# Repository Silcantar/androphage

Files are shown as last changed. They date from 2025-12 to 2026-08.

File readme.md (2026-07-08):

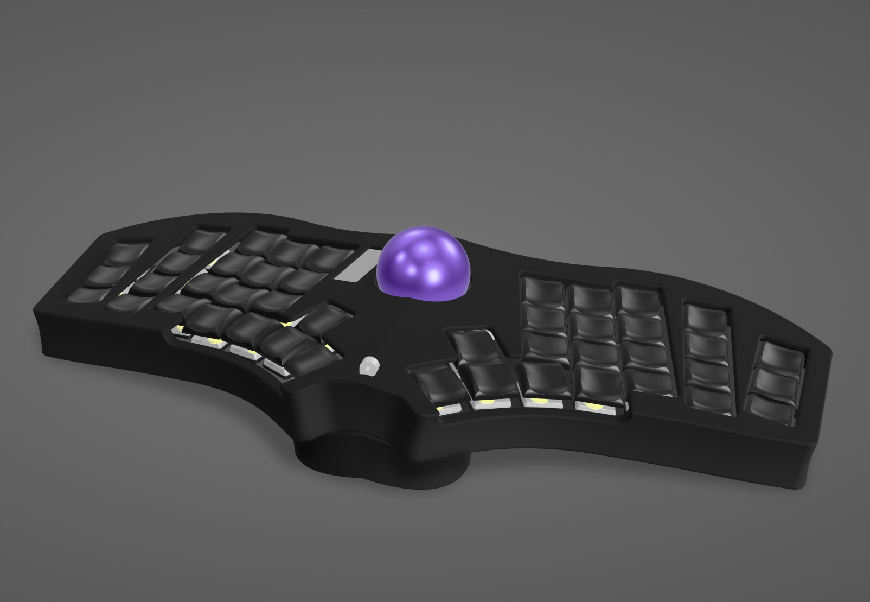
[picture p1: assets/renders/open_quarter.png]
androphage banner


# Androphage

There have been keyboards that are portable and there have been keyboards that
have integrated pointing devices, but to date there haven't been any keyboards
that combine both features. With this new design I intend to change that.

I'm reaching the end of the design phase on my new keyboard, Androphage. It's a
folding unibody split keyboard with 44 keys and a finger trackball in the
center. When the keyboard is closed, all the more delicate components ---
switches, keycaps, screen --- are protected inside the rugged SLS nylon case.
Additionally the trackball is secured in-place by the folding base of the
keyboard.

## Highlights:

- Unibody with fixed 15° split angle\* and 10° tent angle.

- 44 keys: 3x5, plus 4 thumb keys, row 5\*\* middle and ring finger keys, and
  key that can either be a very tucked thumb key or a row 5 index finger key.

- Rugged SLS nylon case.

- NRF52850 microcontroller and ZMK firmware for Bluetooth, dongle, or wired
  connectivity.

- Dual-sensor 34mm trackball is capable of 3-axis control, i.e. twist-to-scroll
  à la Kensington SlimBlade.

- Nice!View or similar screen for layer, pairing, and charging status.

- Low power consumption microcontroller and trackball sensors (PMW3610) paired
  with a 300 mAh LiPo battery for days or weeks of battery life.

- USB-C charging and connectivity.

- Designed for Chicago Steno or KLP Lamé keycaps but can potentially be adapted
  for other low-to-mid-profile keycaps.

- The custom hinges are SLM stainless steel for maximum durability.

- There is space inside the base for storing the charging cable.

- Unfolded dimensions: 290 x 135 x 62 mm

- Folded dimensions: 148 x 135 x 45 mm

\* Measured between the centerline of the keyboard and the axis of the index
finger key column.

\*\* That is, two rows below the home row, equivalent to the modifier row on an
ANSI/ISO keyboard.

## Additional Renders

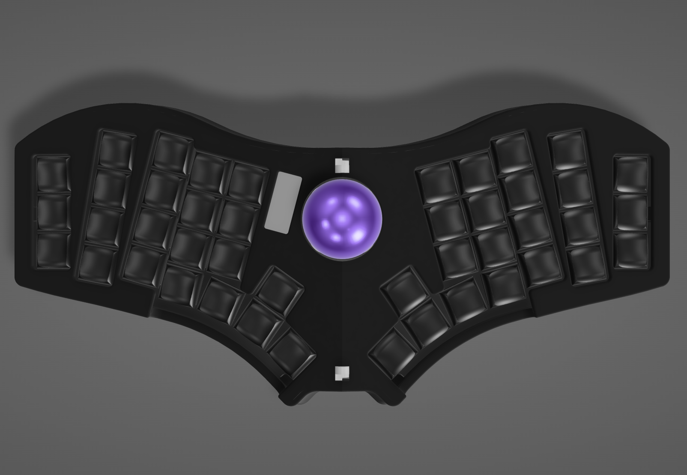
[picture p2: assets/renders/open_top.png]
Opened Top View


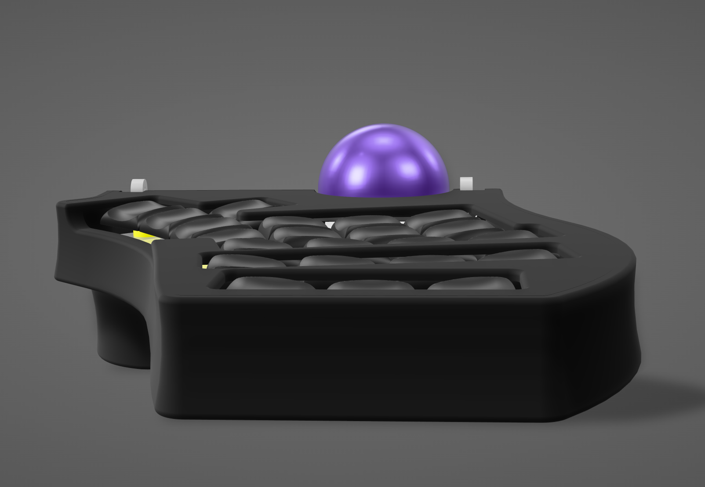
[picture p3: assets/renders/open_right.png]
Opened Right Profile


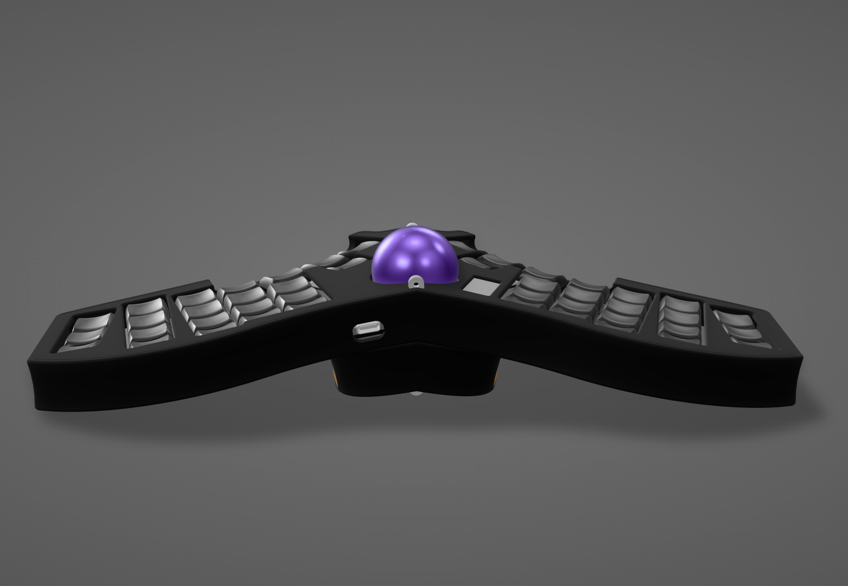
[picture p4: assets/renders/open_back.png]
Opened Back View


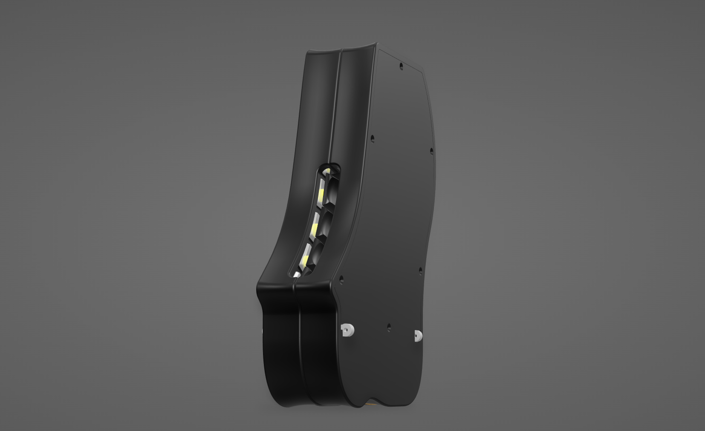
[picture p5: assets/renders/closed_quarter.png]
Closed Quarter View


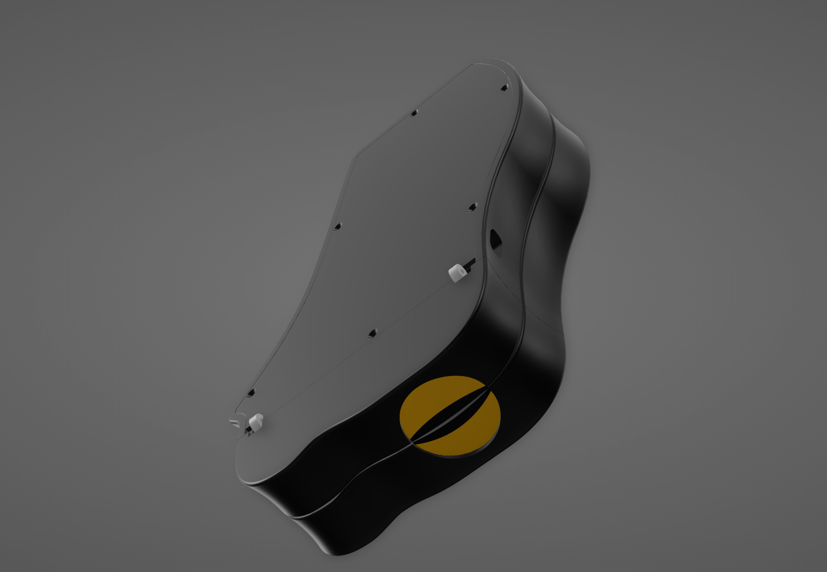
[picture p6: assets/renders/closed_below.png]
Closed Below View


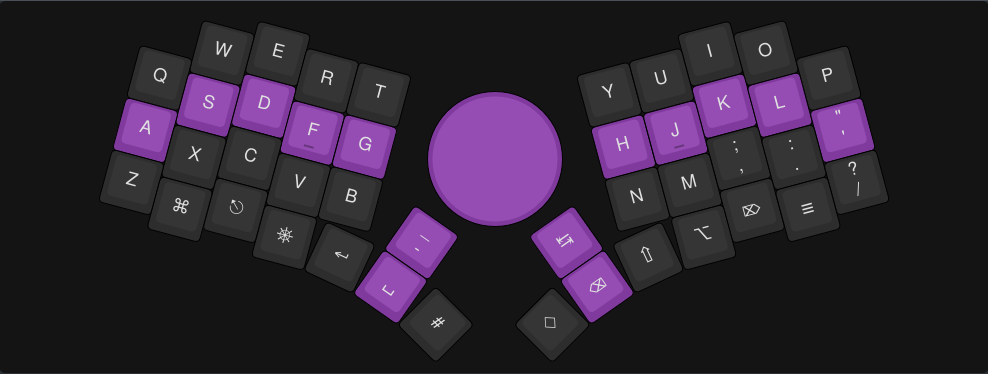
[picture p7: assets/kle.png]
Suggested Key Layout


## Open Source

This project is licensed under the CERN Open Hardware License, Strongly
Reciprocal 2.0.

---

> *Well, I saw the thing comin' out of the sky*
>
> *It had a-one long horn and one big eye*
>
> *I commenced to shakin' and I said, "Ooh-eee!*
>
> *It looks like a purple people eater to me!"*
>
> &mdash;Sheb Wooley

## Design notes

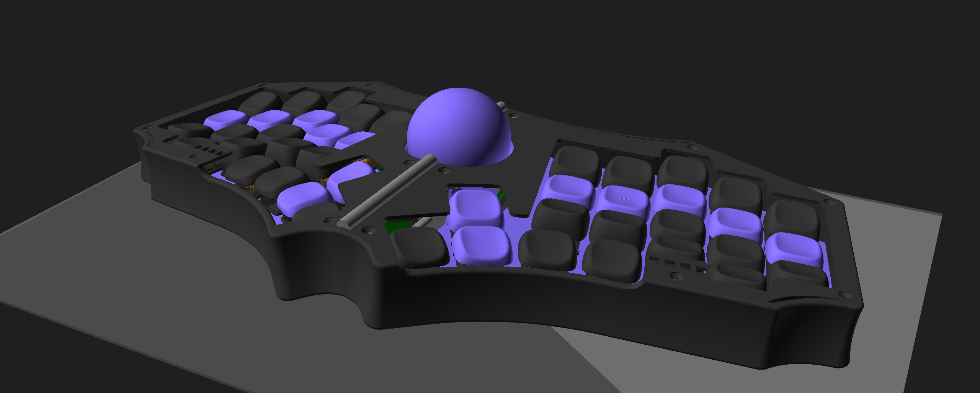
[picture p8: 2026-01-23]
assets/androphage_render.png

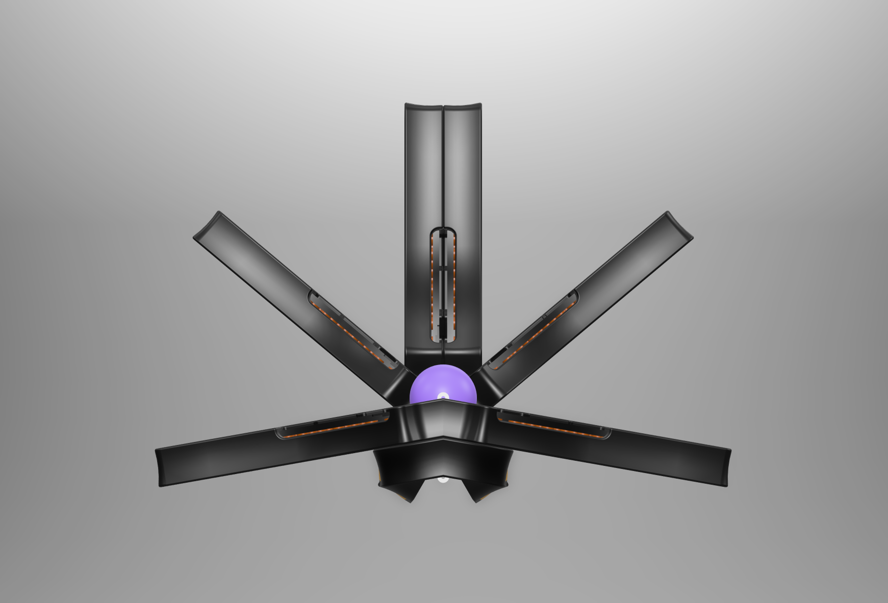
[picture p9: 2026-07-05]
assets/renders/front.png

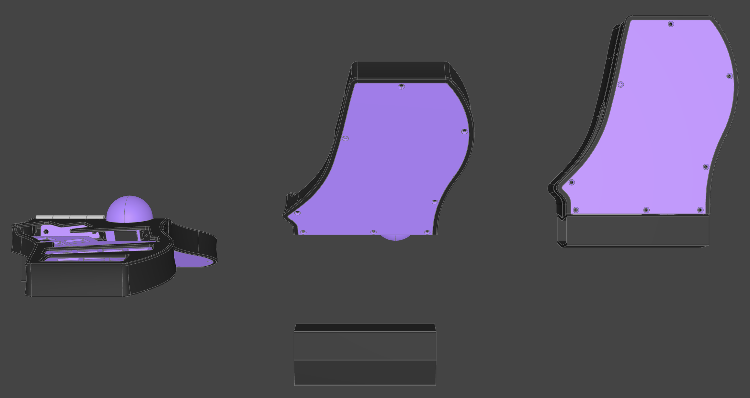
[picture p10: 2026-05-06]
assets/taking_flight.png

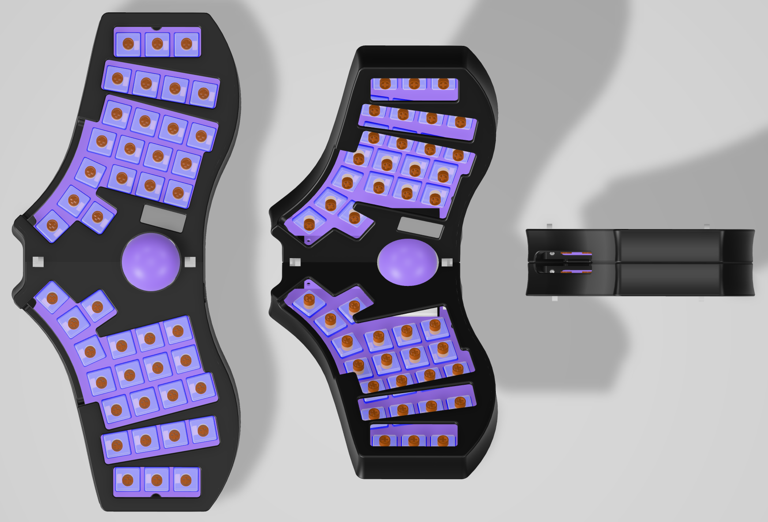
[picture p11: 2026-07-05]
assets/renders/top.png

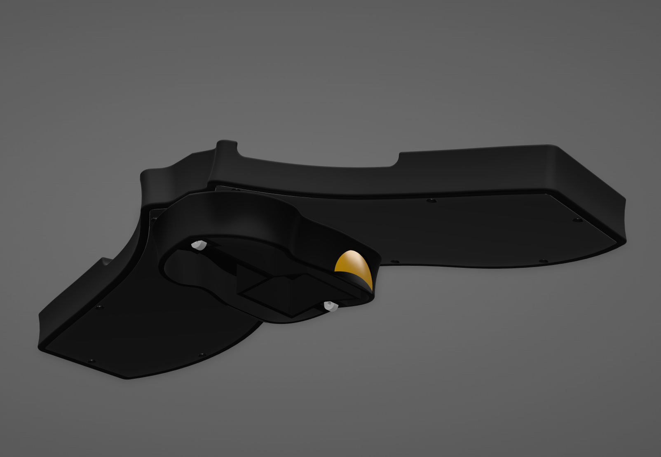
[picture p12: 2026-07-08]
assets/renders/open_below.png

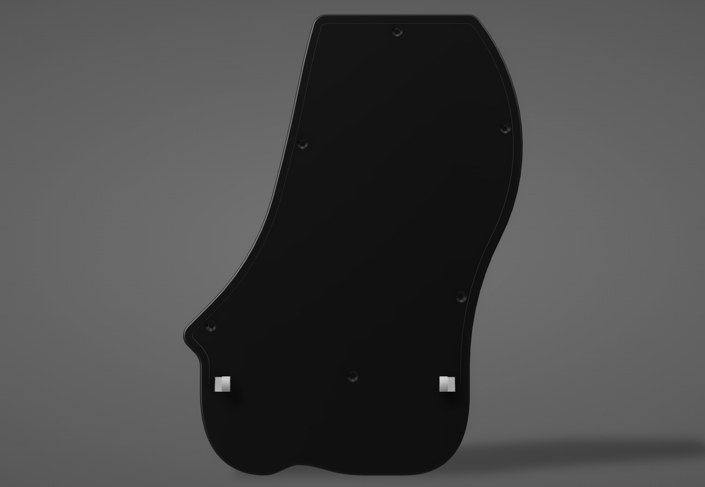
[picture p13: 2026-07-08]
assets/renders/closed_right.png

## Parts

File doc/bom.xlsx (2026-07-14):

Part | Specifications | Mouser Part # | LCSC Part # | Connector PCB | Control PCB | Matrix PCB | Sensor PCB | Other | Quantity | Unit Cost | Total Cost | Source | Link | Notes
Keycap set |  |  |  |  |  |  |  | 0 | 0 | $2.64 | $0.00 | 3dKeycap | https://3dkeycap.com/products/mx-chicago-steno-keycap-set?variant=46916802117890 | Minimum 2 R1, 10 R2, 10 R3, 10 R4, 6/4 R5, 6/8 thumb
BTU | Veichu VCN310 |  |  |  |  |  |  | 4 | 4 | $1.21 | $4.84 | AliBaba | https://www.alibaba.com/product-detail/VEICHU-VCN310-311-New-Stainless-Steel_1601020185379.html
Magnetic pogo pin connector | pair, 12-pin |  |  | 1 |  |  |  |  | 1 | $3.52 | $3.52 | AliBaba | https://www.alibaba.com/product-detail/Fool-proof-Customizable-2-12-Pin_1601813292668.html
Trackball Sensor | PMW-3610DM-SUDU |  |  |  |  |  | 2 |  | 2 | $5.90 | $11.80 | AliExpress | https://www.aliexpress.us/item/3256806932453023.html
Battery | 401230 |  |  |  |  |  |  | 1 | 1 | $7.99 | $7.99 | Amazon | https://a.co/d/0cnfUvY7
Heat-set insert | M2, brass |  |  |  |  |  |  | 32 | 32 | $0.04 | $1.28 | Amazon | https://a.co/d/0f5MURbA
Hot-swap socket |  |  |  |  |  | 44 |  |  | 44 | $0.14 | $6.16 | Amazon | https://a.co/d/0cJAZBIr
Key switch |  |  |  |  |  |  |  | 0 | 0 | $0.39 | $0.00 | Amazon | https://a.co/d/02MneUm9 | Kailh Choc V1/V2, Gateron KS-33
Magnet | 4x2 round |  |  |  |  |  |  | 4 | 4 | $0.03 | $0.12 | Amazon | https://a.co/d/02Mu1WZn
Screw | M2, round, 4mm |  |  |  |  |  |  | 6 | 6 | $0.06 | $0.36 | Amazon | https://a.co/d/04It1t0C
Screw | M2, countersink, 7mm |  |  |  |  |  |  | 26 | 26 | $0.08 | $2.08 | Amazon | https://a.co/d/0gQpGyUt
Trackball | 34-35 mm |  |  |  |  |  |  | 0 | 0 | $11.99 | $0.00 | Amazon | https://a.co/d/06izoJGP
O-Ring | 150 mm x 3.5 mm |  |  |  |  |  |  | 2 | 2 | $1.00 | $2.00 | Amazon | https://a.co/d/0eipM3TN
Bottom Plate | SLS Nylon |  |  |  |  |  |  | 2 | 2 | $7.42 | $14.84 | CraftCloud
Case, Left | SLS Nylon |  |  |  |  |  |  | 1 | 1 | $21.24 | $21.24 | CraftCloud
Case, Right | SLS Nylon |  |  |  |  |  |  | 1 | 1 | $21.24 | $21.24 | CraftCloud
Hinge | SLM 316 stainless steel |  |  |  |  |  |  | 2 | 2 | $4.56 | $9.12 | CraftCloud |  | Set of 4 leaves, unit cost for 20
PCB | VIK PMW3610-narrow |  |  |  |  |  | 2 |  | 2 | $0.63 | $1.26 | JLCPCB
PCB | VIK Magnetic Connector, pair |  |  | 2 |  |  |  |  | 2 | $1.97 | $3.94 | JLCPCB
PCB | Matrix, pair |  |  |  |  | 1 |  |  | 1 | $5.13 | $5.13 | JLCPCB
PCB | Control, pair |  |  |  | 1 |  |  |  | 1 | $5.45 | $5.45 | JLCPCB
VIK nice!nano adapter PCB |  |  |  |  |  |  |  | 1 | 1 | $0.66 | $0.66 | JLCPCB
Taper Pin | 5/0 |  |  |  |  |  |  | 8 | 8 | $0.45 | $3.60 | McMaster | https://www.mcmaster.com/98390A040/
Battery charger |  | 579-MCP73832T-2ACIOT | C38066 |  | 1 |  |  |  | 1 | $0.76 | $0.76 | Mouser | https://mou.sr/3QXacgq
Button Switch |  | 179-TS046643BK160SMT | C2845297 |  |  | 1 |  |  | 1 | $0.18 | $0.18 | Mouser | https://mou.sr/454Uz9S
Capacitor, 100nF |  | 187-CL21B104KBFNNNG | C14663 |  |  |  | 8 |  | 8 | $0.10 | $0.80 | Mouser | https://mou.sr/4pr6I2A
Capacitor, 10nF |  | 187-CL21B103KBANNNC | C57112 |  | 2 |  | 4 |  | 6 | $0.10 | $0.60 | Mouser | https://mou.sr/4fzanb4
Capacitor, 10uF |  | 187-CL21B106KQQNNNF |  |  |  |  | 2 |  | 2 | $0.12 | $0.24 | Mouser | https://mou.sr/44q3UJg
Capacitor, 1uF |  | 187-CL21B105KBFNFNE | C15849 |  |  |  | 2 |  | 2 | $0.12 | $0.24 | Mouser | https://mou.sr/4yljd3D
Capacitor, 3.3uF |  | 187-CL21B335KOQVPNE | C51412 |  |  |  | 2 |  | 2 | $0.38 | $0.76 | Mouser | https://mou.sr/4wMxyEM
Diode |  | 241-1N4148W_R1_00001 | C917030 |  |  | 44 |  |  | 44 | $0.11 | $4.84 | Mouser | https://mou.sr/3RBnNdt | Switch matrix diode
ESD Protection Diode Array |  | 947-RCLAMP0504FBTCT | C2688137 | 6 |  |  |  |  | 6 | $0.89 | $5.34 | Mouser | https://mou.sr/4vZcLxN
Ferrite Bead |  | 875-MI0805K601R-10 | C46550600 | 2 |  | 1 |  |  | 3 | $0.11 | $0.33 | Mouser | https://mou.sr/4pp1IeD
FPC cable |  | 640-512A0101A4064T | C5151956 |  |  |  |  | 7 | 7 | $1.13 | $7.91 | Mouser | https://mou.sr/4hdeuuC | Type A, 0.5mm pitch, 12-pin, [Length]
FPC Connector |  | 640-FFC2B35-12-G | C2906115 | 2 | 8 |  |  | 1 | 11 | $0.43 | $4.73 | Mouser | https://mou.sr/4wNFIwF
FPC connector, mini |  | 640-FFC2B28-12-G | C5213732 |  |  |  | 2 |  | 2 | $0.40 | $0.80 | Mouser | https://mou.sr/3RcmbXu
Fuse |  | 652-MF-PSMF050X-2 | C2833485 | 2 |  | 1 |  |  | 3 | $0.32 | $0.96 | Mouser | https://mou.sr/4ylZUXY
Holyiot 18010 MCU module |  | 713-113990556 |  |  | 1 |  |  |  | 1 | $9.11 | $9.11 | Mouser | https://mou.sr/4pa7teo
I/O Expander |  | 579-MCP23017-E/SS | C506653 |  |  | 2 |  |  | 2 | $1.69 | $3.38 | Mouser | https://mou.sr/4piFMBM
LED ARGB |  | 604-APFA3010SEKJ3ZGK | C2992675 |  |  | 1 |  |  | 1 | $0.76 | $0.76 | Mouser | https://mou.sr/4h7FKe0
Molex Picoblade Connector, 2 pin |  | 538-53398-0271 | C122410 |  | 1 |  |  |  | 1 | $0.54 | $0.54 | Mouser | https://mou.sr/4yl9kTn | Battery connector
Molex Picoblade Connector, 4 pin |  | 538-53398-0471 | C17617036 |  | 1 |  |  |  | 1 | $0.74 | $0.74 | Mouser | https://mou.sr/4feluoj | SWD connector
MOSFET |  | 241-PJA3401AR100001 | C82360 |  | 1 |  |  |  | 1 | $0.33 | $0.33 | Mouser | https://mou.sr/4flJENZ
Resistor, 10 kOhm |  | 603-RC0805FR-0710KL |  |  |  | 12 |  |  | 12 | $0.10 | $1.20 | Mouser | https://mou.sr/4f3aewt
Resistor, 100 kOhm |  | 603-RC0805FR-07100KL |  |  | 1 |  |  |  | 1 | $0.10 | $0.10 | Mouser | https://mou.sr/4vWF2F0
Resistor, 2 kOhm |  | 603-RC0805FR-072KL |  |  | 1 |  |  |  | 1 | $0.10 | $0.10 | Mouser | https://mou.sr/4wdXjxJ
Resistor, 2 MOhm |  | 603-RC0805FR-072ML |  |  | 1 |  | 2 |  | 3 | $0.10 | $0.30 | Mouser | https://mou.sr/4fAjXuf
Resistor, 270 Ohm |  | 603-RC0805FR-07270RL |  |  |  | 1 |  |  | 1 | $0.10 | $0.10 | Mouser | https://mou.sr/4wIlUdJ
Resistor, 330 Ohm |  | 603-RC0805FR-07330RL |  |  |  | 1 |  |  | 1 | $0.10 | $0.10 | Mouser | https://mou.sr/4hdepqP
Resistor, 470 Ohm |  | 603-RC0805FR-07470RL |  |  |  | 1 |  |  | 1 | $0.10 | $0.10 | Mouser | https://mou.sr/4ydr1UW
Resistor, 5.1 kOhm |  | 603-RC0805FR-075K1L |  |  |  | 2 |  |  | 2 | $0.10 | $0.20 | Mouser | https://mou.sr/4wGJ2JJ
Resistor, 8.2 kOhm |  | 603-RC0805FR-078K2L |  |  | 1 |  |  |  | 1 | $0.10 | $0.10 | Mouser | https://mou.sr/3T05u20
Resistor, 820 kOhm |  | 603-RC0805FR-07820KL |  |  | 1 |  |  |  | 1 | $0.10 | $0.10 | Mouser | https://mou.sr/4f0LeWy
Schottky diode |  | 621-1N5819HW-F | C191023 |  | 1 |  |  |  | 1 | $0.29 | $0.29 | Mouser | https://mou.sr/452zhd3
USB-C receptacle |  | 640-USB4930-00-A |  |  |  | 1 |  |  | 1 | $0.52 | $0.52 | Mouser | https://mou.sr/4pkxr0t
Voltage Regulator |  | 757-TCR2EF19LMCT | C146366 |  |  |  | 2 |  | 2 | $0.14 | $0.28 | Mouser | https://mou.sr/4hevIrr | 1.8V 200mA output
Voltage Regulator |  | 595-TLV75733PDYDR | C17703066 |  | 1 |  |  |  | 1 | $0.37 | $0.37 | Mouser | https://mou.sr/4wFoi4W
Switch Plate | Acrylic |  |  |  |  |  |  | 2 | 2 | $3.45 | $6.90 | SendCutSend
Screen | nice!view |  |  |  |  |  |  | 1 | 1 | $20.00 | $20.00 | Typeractive | https://typeractive.xyz/products/nice-view
59 |  | 34 | 21 | 15 | 23 | 113 | 28 | 101 | 280 |  | $200.74

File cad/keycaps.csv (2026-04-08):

Profile | Color | Count 1 | Count 2
R1 | Black | 4 | 0
R1 | Purple | 2 | 6
R2 | Black | 26 | 28
R2 | Purple | 2 | 0
R3 | Purple | 8 | 8
R3 Homing | Purple | 2 | 2

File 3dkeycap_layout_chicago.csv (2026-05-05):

x | y | z | x_rotation | y_rotation | z_rotation | row | size | material | color | legend1_text | legend1_font_family | legend1_font_size | legend1_font_bold | legend1_font_italic | legend1_font_color | legend1_offset_x | legend1_offset_y | legend1_align | legend1_rotation | legend2_text | legend2_font_family | legend2_font_size | legend2_font_bold | legend2_font_italic | legend2_font_color | legend2_offset_x | legend2_offset_y | legend2_align | legend2_rotation | legend3_text | legend3_font_family | legend3_font_size | legend3_font_bold | legend3_font_italic | legend3_font_color | legend3_offset_x | legend3_offset_y | legend3_align | legend3_rotation | legend4_text | legend4_font_family | legend4_font_size | legend4_font_bold | legend4_font_italic | legend4_font_color | legend4_offset_x | legend4_offset_y | legend4_align | legend4_rotation
-90 | 0 | -55.25 | 0 | 0 | 0 | R2 | 1u | resin | black | E | Trebuchet MS | 5 | FALSE | FALSE | white | 0 | 0 | Center | 0 |  |  | null | FALSE | FALSE |  | 0 | 0 | Center | 0 |  |  | null | FALSE | FALSE |  | 0 | 0 | Center | 0 |  |  | null | FALSE | FALSE |  | 0 | 0 | Center | 0
90 | 0 | -55.25 | 0 | 0 | 0 | R2 | 1u | resin | black | I | Trebuchet MS | 5 | FALSE | FALSE | white | 0 | 0 | Center | 0 |  |  | null | FALSE | FALSE |  | 0 | 0 | Center | 0 |  |  | null | FALSE | FALSE |  | 0 | 0 | Center | 0 |  |  | null | FALSE | FALSE |  | 0 | 0 | Center | 0
-108 | 0 | -51 | 0 | 0 | 0 | R2 | 1u | resin | black | W | Trebuchet MS | 5 | FALSE | FALSE | white | 0 | 0 | Center | 0 |  |  | null | FALSE | FALSE |  | 0 | 0 | Center | 0 |  |  | null | FALSE | FALSE |  | 0 | 0 | Center | 0 |  |  | null | FALSE | FALSE |  | 0 | 0 | Center | 0
-72 | 0 | -51 | 0 | 0 | 0 | R2 | 1u | resin | black | R | Trebuchet MS | 5 | FALSE | FALSE | white | 0 | 0 | Center | 0 |  |  | null | FALSE | FALSE |  | 0 | 0 | Center | 0 |  |  | null | FALSE | FALSE |  | 0 | 0 | Center | 0 |  |  | null | FALSE | FALSE |  | 0 | 0 | Center | 0
-54 | 0 | -51 | 0 | 0 | 0 | R2 | 1u | resin | black | T | Trebuchet MS | 5 | FALSE | FALSE | white | 0 | 0 | Center | 0 |  |  | null | FALSE | FALSE |  | 0 | 0 | Center | 0 |  |  | null | FALSE | FALSE |  | 0 | 0 | Center | 0 |  |  | null | FALSE | FALSE |  | 0 | 0 | Center | 0
54 | 0 | -51 | 0 | 0 | 0 | R2 | 1u | resin | black | Y | Trebuchet MS | 5 | FALSE | FALSE | white | 0 | 0 | Center | 0 |  |  | null | FALSE | FALSE |  | 0 | 0 | Center | 0 |  |  | null | FALSE | FALSE |  | 0 | 0 | Center | 0 |  |  | null | FALSE | FALSE |  | 0 | 0 | Center | 0
72 | 0 | -51 | 0 | 0 | 0 | R2 | 1u | resin | black | U | Trebuchet MS | 5 | FALSE | FALSE | white | 0 | 0 | Center | 0 |  |  | null | FALSE | FALSE |  | 0 | 0 | Center | 0 |  |  | null | FALSE | FALSE |  | 0 | 0 | Center | 0 |  |  | null | FALSE | FALSE |  | 0 | 0 | Center | 0
108 | 0 | -51 | 0 | 0 | 0 | R2 | 1u | resin | black | O | Trebuchet MS | 5 | FALSE | FALSE | white | 0 | 0 | Center | 0 |  |  | null | FALSE | FALSE |  | 0 | 0 | Center | 0 |  |  | null | FALSE | FALSE |  | 0 | 0 | Center | 0 |  |  | null | FALSE | FALSE |  | 0 | 0 | Center | 0
-126 | 0 | -38.25 | 0 | 0 | 0 | R2 | 1u | resin | black | Q | Trebuchet MS | 5 | FALSE | FALSE | white | 0 | 0 | Center | 0 |  |  | null | FALSE | FALSE |  | 0 | 0 | Center | 0 |  |  | null | FALSE | FALSE |  | 0 | 0 | Center | 0 |  |  | null | FALSE | FALSE |  | 0 | 0 | Center | 0
-90 | 0 | -38.25 | 0 | 0 | 0 | R3 | 1u | resin | purple | D | Trebuchet MS | 5 | FALSE | FALSE | white | 0 | 0 | Center | 0 |  |  | null | FALSE | FALSE |  | 0 | 0 | Center | 0 |  |  | null | FALSE | FALSE |  | 0 | 0 | Center | 0 |  |  | null | FALSE | FALSE |  | 0 | 0 | Center | 0
90 | 0 | -38.25 | 0 | 0 | 0 | R3 | 1u | resin | purple | K | Trebuchet MS | 5 | FALSE | FALSE | white | 0 | 0 | Center | 0 |  |  | null | FALSE | FALSE |  | 0 | 0 | Center | 0 |  |  | null | FALSE | FALSE |  | 0 | 0 | Center | 0 |  |  | null | FALSE | FALSE |  | 0 | 0 | Center | 0
126 | 0 | -38.25 | 0 | 0 | 0 | R2 | 1u | resin | black | P | Trebuchet MS | 5 | FALSE | FALSE | white | 0 | 0 | Center | 0 |  |  | null | FALSE | FALSE |  | 0 | 0 | Center | 0 |  |  | null | FALSE | FALSE |  | 0 | 0 | Center | 0 |  |  | null | FALSE | FALSE |  | 0 | 0 | Center | 0
-108 | 0 | -34 | 0 | 0 | 0 | R3 | 1u | resin | purple | S | Trebuchet MS | 5 | FALSE | FALSE | white | 0 | 0 | Center | 0 |  |  | null | FALSE | FALSE |  | 0 | 0 | Center | 0 |  |  | null | FALSE | FALSE |  | 0 | 0 | Center | 0 |  |  | null | FALSE | FALSE |  | 0 | 0 | Center | 0
-72 | 0 | -34 | 0 | 0 | 0 | R3 | 1u-homing | resin | purple | F | Trebuchet MS | 5 | FALSE | FALSE | white | 0 | 0 | Center | 0 |  |  | null | FALSE | FALSE |  | 0 | 0 | Center | 0 |  |  | null | FALSE | FALSE |  | 0 | 0 | Center | 0 |  |  | null | FALSE | FALSE |  | 0 | 0 | Center | 0
-54 | 0 | -34 | 0 | 0 | 0 | R3 | 1u | resin | purple | G | Trebuchet MS | 5 | FALSE | FALSE | white | 0 | 0 | Center | 0 |  |  | null | FALSE | FALSE |  | 0 | 0 | Center | 0 |  |  | null | FALSE | FALSE |  | 0 | 0 | Center | 0 |  |  | null | FALSE | FALSE |  | 0 | 0 | Center | 0
54 | 0 | -34 | 0 | 0 | 0 | R3 | 1u | resin | purple | H | Trebuchet MS | 5 | FALSE | FALSE | white | 0 | 0 | Center | 0 |  |  | null | FALSE | FALSE |  | 0 | 0 | Center | 0 |  |  | null | FALSE | FALSE |  | 0 | 0 | Center | 0 |  |  | null | FALSE | FALSE |  | 0 | 0 | Center | 0
72 | 0 | -34 | 0 | 0 | 0 | R3 | 1u-homing | resin | purple | J | Trebuchet MS | 5 | FALSE | FALSE | white | 0 | 0 | Center | 0 |  |  | null | FALSE | FALSE |  | 0 | 0 | Center | 0 |  |  | null | FALSE | FALSE |  | 0 | 0 | Center | 0 |  |  | null | FALSE | FALSE |  | 0 | 0 | Center | 0
108 | 0 | -34 | 0 | 0 | 0 | R3 | 1u | resin | purple | L | Trebuchet MS | 5 | FALSE | FALSE | white | 0 | 0 | Center | 0 |  |  | null | FALSE | FALSE |  | 0 | 0 | Center | 0 |  |  | null | FALSE | FALSE |  | 0 | 0 | Center | 0 |  |  | null | FALSE | FALSE |  | 0 | 0 | Center | 0
-126 | 0 | -21.25 | 0 | 0 | 0 | R3 | 1u | resin | purple | A | Trebuchet MS | 5 | FALSE | FALSE | white | 0 | 0 | Center | 0 |  |  | null | FALSE | FALSE |  | 0 | 0 | Center | 0 |  |  | null | FALSE | FALSE |  | 0 | 0 | Center | 0 |  |  | null | FALSE | FALSE |  | 0 | 0 | Center | 0
-90 | 0 | -21.25 | 0 | 0 | 0 | R4 | 1u | resin | black | C | Trebuchet MS | 5 | FALSE | FALSE | white | 0 | 0 | Center | 0 |  |  | null | FALSE | FALSE |  | 0 | 0 | Center | 0 |  |  | null | FALSE | FALSE |  | 0 | 0 | Center | 0 |  |  | null | FALSE | FALSE |  | 0 | 0 | Center | 0
90 | 0 | -21.25 | 0 | 0 | 0 | R4 | 1u | resin | black | , | Trebuchet MS | 5 | FALSE | FALSE | white | 0 | 0 | Center | 0 |  |  | null | FALSE | FALSE |  | 0 | 0 | Center | 0 |  |  | null | FALSE | FALSE |  | 0 | 0 | Center | 0 |  |  | null | FALSE | FALSE |  | 0 | 0 | Center | 0
126 | 0 | -21.25 | 0 | 0 | 0 | R3 | 1u | resin | purple | ; | Trebuchet MS | 5 | FALSE | FALSE | white | 0 | 0 | Center | 0 |  |  | null | FALSE | FALSE |  | 0 | 0 | Center | 0 |  |  | null | FALSE | FALSE |  | 0 | 0 | Center | 0 |  |  | null | FALSE | FALSE |  | 0 | 0 | Center | 0
-108 | 0 | -17 | 0 | 0 | 0 | R4 | 1u | resin | black | X | Trebuchet MS | 5 | FALSE | FALSE | white | 0 | 0 | Center | 0 |  |  | null | FALSE | FALSE |  | 0 | 0 | Center | 0 |  |  | null | FALSE | FALSE |  | 0 | 0 | Center | 0 |  |  | null | FALSE | FALSE |  | 0 | 0 | Center | 0
-72 | 0 | -17 | 0 | 0 | 0 | R4 | 1u | resin | black | V | Trebuchet MS | 5 | FALSE | FALSE | white | 0 | 0 | Center | 0 |  |  | null | FALSE | FALSE |  | 0 | 0 | Center | 0 |  |  | null | FALSE | FALSE |  | 0 | 0 | Center | 0 |  |  | null | FALSE | FALSE |  | 0 | 0 | Center | 0
-54 | 0 | -17 | 0 | 0 | 0 | R4 | 1u | resin | black | B | Trebuchet MS | 5 | FALSE | FALSE | white | 0 | 0 | Center | 0 |  |  | null | FALSE | FALSE |  | 0 | 0 | Center | 0 |  |  | null | FALSE | FALSE |  | 0 | 0 | Center | 0 |  |  | null | FALSE | FALSE |  | 0 | 0 | Center | 0
-36 | 0 | -17 | 0 | 0 | 0 | R1 | 1u | resin | purple | TabL | Trebuchet MS | 5 | FALSE | FALSE | white | 0 | 0 | Center | 0 |  |  | null | FALSE | FALSE |  | 0 | 0 | Center | 0 |  |  | null | FALSE | FALSE |  | 0 | 0 | Center | 0 |  |  | null | FALSE | FALSE |  | 0 | 0 | Center | 0
36 | 0 | -17 | 0 | 0 | 0 | R1 | 1u | resin | purple | TabR | Trebuchet MS | 5 | FALSE | FALSE | white | 0 | 0 | Center | 0 |  |  | null | FALSE | FALSE |  | 0 | 0 | Center | 0 |  |  | null | FALSE | FALSE |  | 0 | 0 | Center | 0 |  |  | null | FALSE | FALSE |  | 0 | 0 | Center | 0
54 | 0 | -17 | 0 | 0 | 0 | R4 | 1u | resin | black | N | Trebuchet MS | 5 | FALSE | FALSE | white | 0 | 0 | Center | 0 |  |  | null | FALSE | FALSE |  | 0 | 0 | Center | 0 |  |  | null | FALSE | FALSE |  | 0 | 0 | Center | 0 |  |  | null | FALSE | FALSE |  | 0 | 0 | Center | 0
72 | 0 | -17 | 0 | 0 | 0 | R4 | 1u | resin | black | M | Trebuchet MS | 5 | FALSE | FALSE | white | 0 | 0 | Center | 0 |  |  | null | FALSE | FALSE |  | 0 | 0 | Center | 0 |  |  | null | FALSE | FALSE |  | 0 | 0 | Center | 0 |  |  | null | FALSE | FALSE |  | 0 | 0 | Center | 0
108 | 0 | -17 | 0 | 0 | 0 | R4 | 1u | resin | black | . | Trebuchet MS | 5 | FALSE | FALSE | white | 0 | 0 | Center | 0 |  |  | null | FALSE | FALSE |  | 0 | 0 | Center | 0 |  |  | null | FALSE | FALSE |  | 0 | 0 | Center | 0 |  |  | null | FALSE | FALSE |  | 0 | 0 | Center | 0
-126 | 0 | -4.25 | 0 | 0 | 0 | R4 | 1u | resin | black | Z | Trebuchet MS | 5 | FALSE | FALSE | white | 0 | 0 | Center | 0 |  |  | null | FALSE | FALSE |  | 0 | 0 | Center | 0 |  |  | null | FALSE | FALSE |  | 0 | 0 | Center | 0 |  |  | null | FALSE | FALSE |  | 0 | 0 | Center | 0
-90 | 0 | -4.25 | 0 | 0 | 0 | R1 | 1u | resin | black | Esc | Trebuchet MS | 5 | FALSE | FALSE | white | 0 | 0 | Center | 0 |  |  | null | FALSE | FALSE |  | 0 | 0 | Center | 0 |  |  | null | FALSE | FALSE |  | 0 | 0 | Center | 0 |  |  | null | FALSE | FALSE |  | 0 | 0 | Center | 0
90 | 0 | -4.25 | 0 | 0 | 0 | R1 | 1u | resin | black | Del | Trebuchet MS | 5 | FALSE | FALSE | white | 0 | 0 | Center | 0 |  |  | null | FALSE | FALSE |  | 0 | 0 | Center | 0 |  |  | null | FALSE | FALSE |  | 0 | 0 | Center | 0 |  |  | null | FALSE | FALSE |  | 0 | 0 | Center | 0
126 | 0 | -4.25 | 0 | 0 | 0 | R4 | 1u | resin | black | / | Trebuchet MS | 5 | FALSE | FALSE | white | 0 | 0 | Center | 0 |  |  | null | FALSE | FALSE |  | 0 | 0 | Center | 0 |  |  | null | FALSE | FALSE |  | 0 | 0 | Center | 0 |  |  | null | FALSE | FALSE |  | 0 | 0 | Center | 0
-108 | 0 | 0 | 0 | 0 | 0 | R1 | 1u | resin | black | CW | Trebuchet MS | 5 | FALSE | FALSE | white | 0 | 0 | Center | 0 |  |  | null | FALSE | FALSE |  | 0 | 0 | Center | 0 |  |  | null | FALSE | FALSE |  | 0 | 0 | Center | 0 |  |  | null | FALSE | FALSE |  | 0 | 0 | Center | 0
-72 | 0 | 0 | 0 | 0 | 0 | R1 | 1u | resin | black | Ctrl | Trebuchet MS | 5 | FALSE | FALSE | white | 0 | 0 | Center | 0 |  |  | null | FALSE | FALSE |  | 0 | 0 | Center | 0 |  |  | null | FALSE | FALSE |  | 0 | 0 | Center | 0 |  |  | null | FALSE | FALSE |  | 0 | 0 | Center | 0
-54 | 0 | 0 | 0 | 0 | 0 | R2 | 1u | resin | black | Ret | Trebuchet MS | 5 | FALSE | FALSE | white | 0 | 0 | Center | 0 |  |  | null | FALSE | FALSE |  | 0 | 0 | Center | 0 |  |  | null | FALSE | FALSE |  | 0 | 0 | Center | 0 |  |  | null | FALSE | FALSE |  | 0 | 0 | Center | 0
-36 | 0 | 0 | 0 | 0 | 0 | R2 | 1u | resin | purple | Spc | Trebuchet MS | 5 | FALSE | FALSE | white | 0 | 0 | Center | 0 |  |  | null | FALSE | FALSE |  | 0 | 0 | Center | 0 |  |  | null | FALSE | FALSE |  | 0 | 0 | Center | 0 |  |  | null | FALSE | FALSE |  | 0 | 0 | Center | 0
-18 | 0 | 0 | 0 | 0 | 0 | R2 | 1u | resin | black | Num | Trebuchet MS | 5 | FALSE | FALSE | white | 0 | 0 | Center | 0 |  |  | null | FALSE | FALSE |  | 0 | 0 | Center | 0 |  |  | null | FALSE | FALSE |  | 0 | 0 | Center | 0 |  |  | null | FALSE | FALSE |  | 0 | 0 | Center | 0
18 | 0 | 0 | 0 | 0 | 0 | R2 | 1u | resin | black | Nav | Trebuchet MS | 5 | FALSE | FALSE | white | 0 | 0 | Center | 0 |  |  | null | FALSE | FALSE |  | 0 | 0 | Center | 0 |  |  | null | FALSE | FALSE |  | 0 | 0 | Center | 0 |  |  | null | FALSE | FALSE |  | 0 | 0 | Center | 0
36 | 0 | 0 | 0 | 0 | 0 | R2 | 1u | resin | purple | Bspc | Trebuchet MS | 5 | FALSE | FALSE | white | 0 | 0 | Center | 0 |  |  | null | FALSE | FALSE |  | 0 | 0 | Center | 0 |  |  | null | FALSE | FALSE |  | 0 | 0 | Center | 0 |  |  | null | FALSE | FALSE |  | 0 | 0 | Center | 0
54 | 0 | 0 | 0 | 0 | 0 | R2 | 1u | resin | black | Sft | Trebuchet MS | 5 | FALSE | FALSE | white | 0 | 0 | Center | 0 |  |  | null | FALSE | FALSE |  | 0 | 0 | Center | 0 |  |  | null | FALSE | FALSE |  | 0 | 0 | Center | 0 |  |  | null | FALSE | FALSE |  | 0 | 0 | Center | 0
72 | 0 | 0 | 0 | 0 | 0 | R1 | 1u | resin | black | Menu | Trebuchet MS | 5 | FALSE | FALSE | white | 0 | 0 | Center | 0 |  |  | null | FALSE | FALSE |  | 0 | 0 | Center | 0 |  |  | null | FALSE | FALSE |  | 0 | 0 | Center | 0 |  |  | null | FALSE | FALSE |  | 0 | 0 | Center | 0
108 | 0 | 0 | 0 | 0 | 0 | R1 | 1u | resin | black | Caps | Trebuchet MS | 5 | FALSE | FALSE | white | 0 | 0 | Center | 0 |  |  | null | FALSE | FALSE |  | 0 | 0 | Center | 0 |  |  | null | FALSE | FALSE |  | 0 | 0 | Center | 0 |  |  | null | FALSE | FALSE |  | 0 | 0 | Center | 0
-72 | 0 | 17 | 0 | 0 | 0 | R2 | 1u | resin | black | Ctrl | Trebuchet MS | 5 | FALSE | FALSE | white | 0 | 0 | Center | 0 |  |  | null | FALSE | FALSE |  | 0 | 0 | Center | 0 |  |  | null | FALSE | FALSE |  | 0 | 0 | Center | 0 |  |  | null | FALSE | FALSE |  | 0 | 0 | Center | 0
72 | 0 | 17 | 0 | 0 | 0 | R2 | 1u | resin | black | Menu | Trebuchet MS | 5 | FALSE | FALSE | white | 0 | 0 | Center | 0 |  |  | null | FALSE | FALSE |  | 0 | 0 | Center | 0 |  |  | null | FALSE | FALSE |  | 0 | 0 | Center | 0 |  |  | null | FALSE | FALSE |  | 0 | 0 | Center | 0

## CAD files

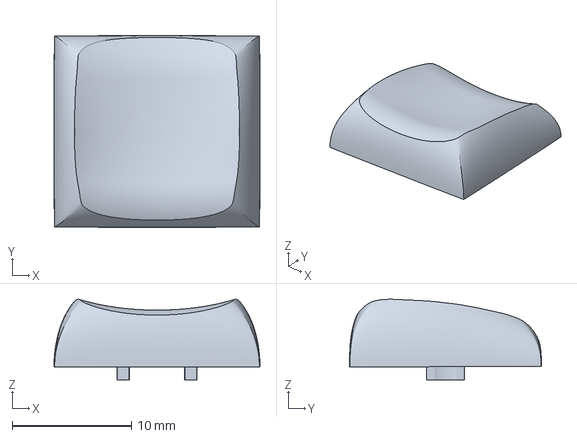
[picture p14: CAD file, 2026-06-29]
cad/components/keycaps/Choc_Chicago_Steno_R1.3mf
17.3 x 16.1 x 6.77 mm

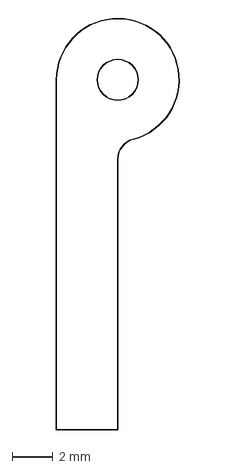
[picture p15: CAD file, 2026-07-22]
cad/production/hinge_knuckle_plate.dxf
6.22 x 20.2 mm

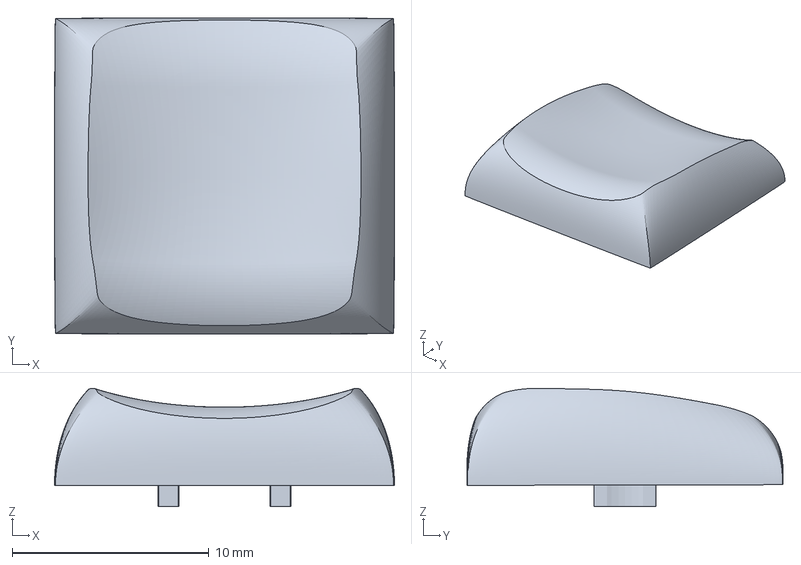
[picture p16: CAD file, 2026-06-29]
cad/components/keycaps/Choc_Chicago_Steno_R2.3mf
17.3 x 16.1 x 6.02 mm

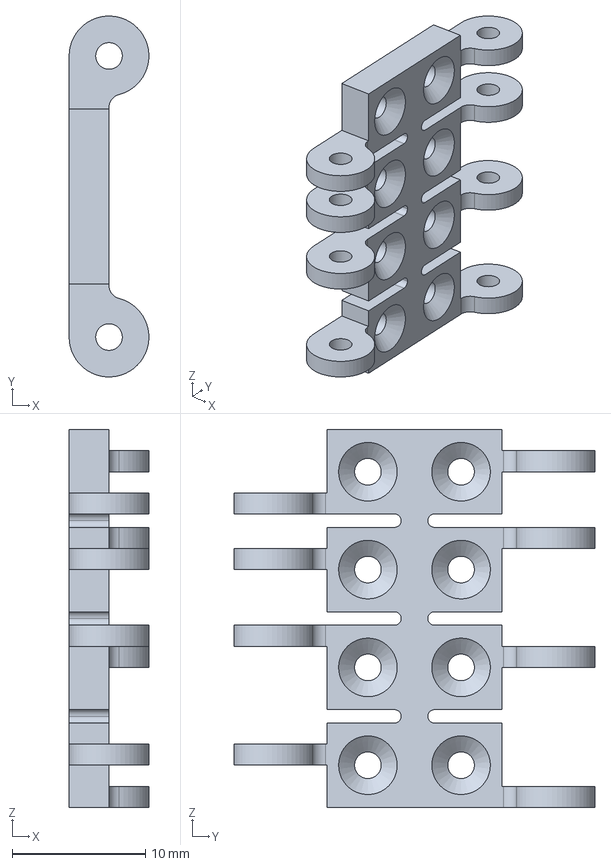
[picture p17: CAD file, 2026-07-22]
cad/production/knife_hinge_multi.step
6.00 x 27.1 x 28.4 mm

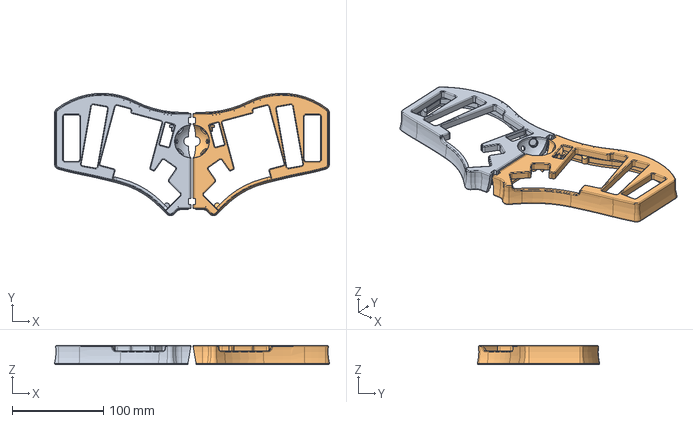
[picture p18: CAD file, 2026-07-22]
cad/production/case_combined.step
300.9 x 133.9 x 20.8 mm

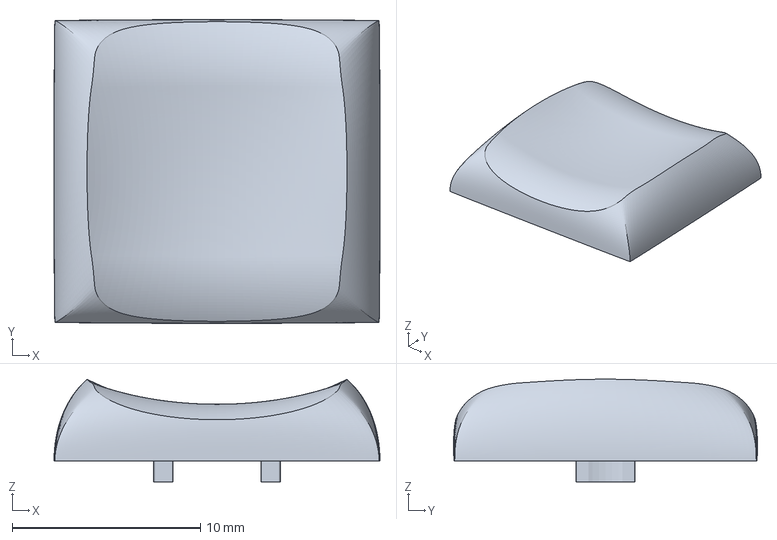
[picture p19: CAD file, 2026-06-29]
cad/components/keycaps/Choc_Chicago_Steno_R3.3mf
17.3 x 16.1 x 5.45 mm

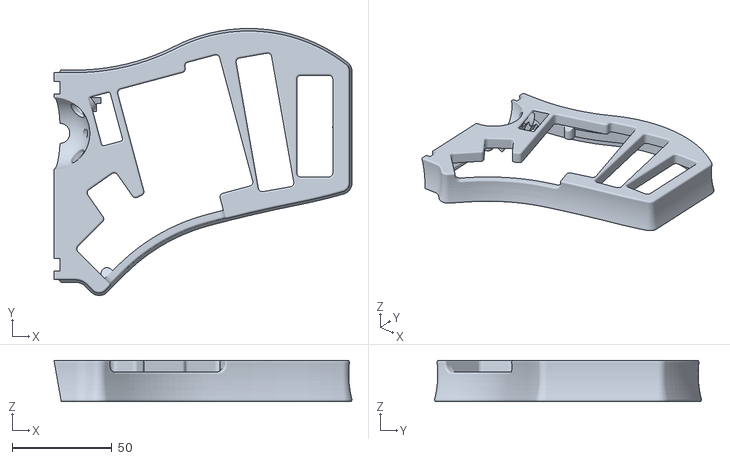
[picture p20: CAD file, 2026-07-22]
cad/production/case_right.stl
149.4 x 133.9 x 20.8

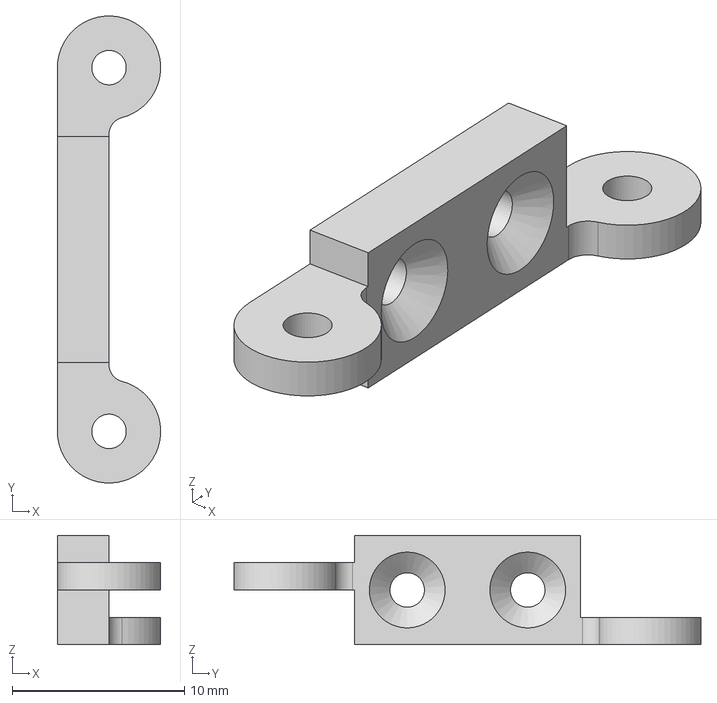
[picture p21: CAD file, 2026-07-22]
cad/production/knife_hinge.step
6.00 x 27.1 x 6.35 mm

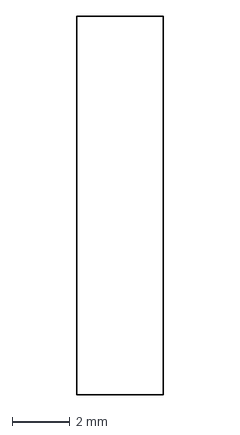
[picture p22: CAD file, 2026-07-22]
cad/production/hinge_plate.dxf
3.00 x 13.1 mm

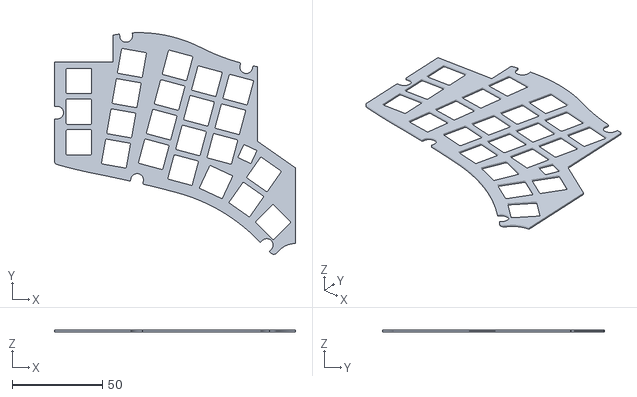
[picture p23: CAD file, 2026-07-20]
cad/production/switch.stl
133.6 x 122.9 x 1.00

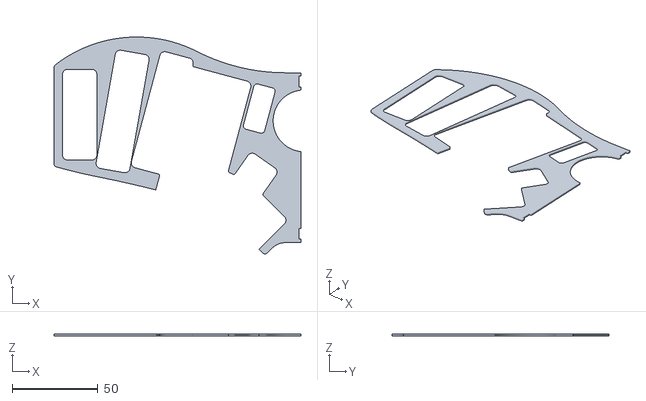
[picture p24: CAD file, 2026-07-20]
cad/production/top.stl
144.1 x 126.5 x 1.00

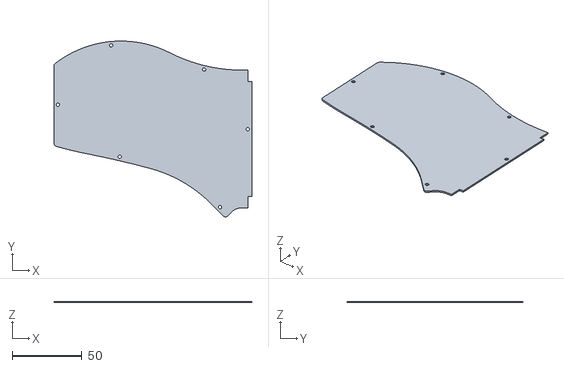
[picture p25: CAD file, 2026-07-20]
cad/production/bottom.stl
141.9 x 126.0 x 1

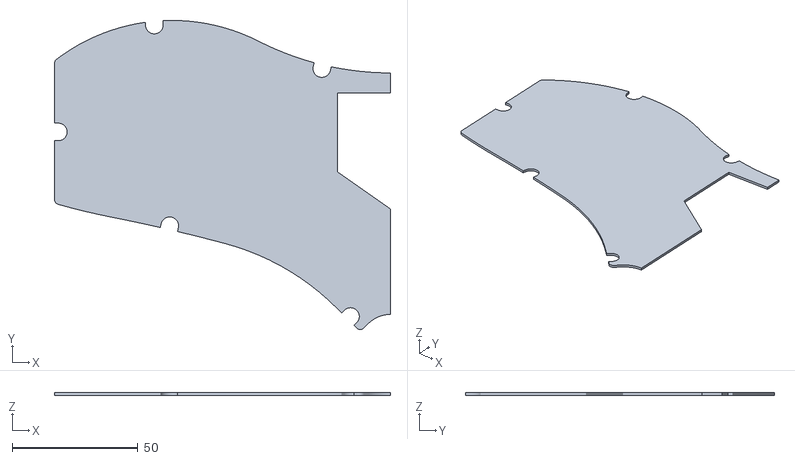
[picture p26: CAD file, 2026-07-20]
cad/production/pcb.stl
133.6 x 122.9 x 1.00

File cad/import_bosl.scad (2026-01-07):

/*******************************************************************************\
|					Import the necessary libraries from BOSL2. 					|
|							Copyright 2026 Joshua Lucas 						|
\*******************************************************************************/

// Suppress the warning about not importing the STD library.
BOSL2_NO_STD_WARNING = true;

include <BOSL2/utility.scad>

include <BOSL2/vectors.scad>

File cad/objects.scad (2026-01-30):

/*******************************************************************************\
                                DEPRECATED
|				Map all Androphage keyboard parameters to objects.				|
|							Copyright 2026 Joshua Lucas 						|
\*******************************************************************************/

Battery = object ( [
    [ "color",		Battery_color	],
    [ "size",		Battery_size	],
    [ "visible",	Battery_visible	],
] );

/*******************************************************************************\
|								Center Block									|
\*******************************************************************************/

CenterBlock = object ( [
    [ "color",			CenterBlock_color			],
    [ "height",			CenterBlock_height			],
    [ "ribSize",		CenterBlock_ribSize			],
    [ "screwCount",		CenterBlock_screwCount		],
    [ "visible",        CenterBlock_visible         ],
    [ "wallThickness",	CenterBlock_wallThickness	],
] );

/*******************************************************************************\
|								Thumb Cluster									|
\*******************************************************************************/

Cluster = object ( [
    [ "angle",			Cluster_angle			],
    [ "columnCounts",	Cluster_columnCounts	],
    [ "columnOffsets",	Cluster_columnOffsets	],
    [ "cutouts",		Cluster_cutouts			],
    [ "fiveThumbKeys",  Cluster_fiveThumbKeys   ],
    [ "innerThumbKeyAngle", Cluster_innerThumbKeyAngle ],
    [ "radius",			Cluster_radius			],
    [ "radius_mm",		Cluster_radius_mm		],
] );

/*******************************************************************************\
|									Columns										|
\*******************************************************************************/

Column_Inner = object ( [
    [ "count",	Column_inner_count	],
    [ "offset",	Column_inner_offset	],
] );

Column_Index = object ( [
    [ "count",	Column_index_count	],
    [ "offset",	Column_index_offset	],
] );

Column_Middle = object ( [
    [ "count",	Column_middle_count		],
    [ "offset",	Column_middle_offset	],
] );

Column_Ring = object ( [
    [ "count",	Column_ring_count	],
    [ "offset",	Column_ring_offset	],
] );

Column_Pinky = object ( [
    [ "count",	Column_pinky_count	],
    [ "offset",	Column_pinky_offset	],
] );

Column_Outer = object ( [
    [ "count",	Column_outer_count	],
    [ "offset",	Column_outer_offset	],
] );

Column = object ( [
    [ "Inner",		Column_Inner		],
    [ "Index",		Column_Index		],
    [ "Middle",		Column_Middle		],
    [ "Ring",		Column_Ring			],
    [ "Pinky",		Column_Pinky		],
    [ "Outer",		Column_Outer		],
    [ "last",		Column_last			],
    [ "connectors",	Column_connectors	],
    [ "count",		Column_count		],
    [ "counts",		Column_counts		],
    [ "cutouts",	Column_cutouts		],
    [ "offsets",	Column_offsets		],
] );

/*******************************************************************************\
|										Desk									|
\*******************************************************************************/

Desk = object ( [
    [ "color",		Desk_color		],
    [ "position",	Desk_position	],
    [ "size",		Desk_size		],
    [ "visible",    Desk_visible    ],
] );

/*******************************************************************************\
|									Fasteners									|
\*******************************************************************************/

Screw = object ( [
    [ "centerX",		Screw_centerX		],
    [ "color",			Screw_color			],
    [ "diameter",		Screw_diameter		],
    [ "headAngle",		Screw_headAngle		],
    [ "headDiameter",	Screw_headDiameter	],
    [ "minorDiameter",	Screw_minorDiameter	],
    [ "offset",			Screw_offset		],
    [ "visible",        Screw_visible       ],
] );

Insert = object ( [
    [ "color",			Insert_color			],
    [ "diameter",		Insert_diameter			],
    [ "height",			Insert_height			],
    [ "holeDiameter",	Insert_holeDiameter		],
    [ "holeDepth",		Insert_holeDepth		],
    [ "visible",        Insert_visible          ],
    [ "wallThickness",	Insert_wallThickness	],
] );

/*******************************************************************************\
|										Frame									|
\*******************************************************************************/

Frame = object ( [
    [ "color",			Frame_color			],
    [ "chordAngle",		Frame_chordAngle	],
    [ "extraLength",	Frame_extraLength	],
    [ "filletRadius",	Frame_filletRadius	],
    [ "height",			Frame_height		],
    [ "lipDepth",		Frame_lipDepth		],
    [ "mainRadius",		Frame_mainRadius	],
    [ "notchDepth",		Frame_notchDepth	],
    [ "path",			Frame_path			],
    [ "size",			Frame_size			],
    [ "thickness",		Frame_thickness		],
    [ "visible",		Frame_visible		],
] );

/*******************************************************************************\
|									Halves										|
\*******************************************************************************/

Halves = object ( [
    [ "angles",		Halves_angles		],
    [ "clearance",	Halves_clearance	],
] );

/*******************************************************************************\
|									Hinge										|
\*******************************************************************************/

Hinge_Back = object ( [
    [ "length",		Hinge_Back_length	],
    [ "position",	Hinge_Back_position	],
] );

Hinge_Front = object ( [
    [ "length",		Hinge_Front_length		],
    [ "position",	Hinge_Front_position	],
] );

Hinge = object ( [
    [ "Back",			Hinge_Back							],
    [ "Front",			Hinge_Front							],
    [ "color",			Hinge_color							],
    [ "diameter",		Hinge_diameter * Hinge_scale		],
    [ "knuckleDepth",	Hinge_knuckleDepth * Hinge_scale	],
    [ "pinDiameter",	Hinge_pinDiameter * Hinge_scale		],
    [ "leafThickness",	Hinge_leafThickness * Hinge_scale	],
    [ "leafWidth",		Hinge_leafWidth * Hinge_scale		],
    [ "length",         Hinge_length                        ],
    [ "visible",        Hinge_visible                       ],
] );

/*******************************************************************************\
|									Keys										|
\*******************************************************************************/

Key = object ( [
    [ "height",		Key_height		],
    [ "mxSpacing",	Key_mxSpacing	],
    [ "spacing",	Key_spacing		],
] );

/*******************************************************************************\
|									Keycaps										|
\*******************************************************************************/

Keycap = object ( [
    [ "clearance", 		Keycap_clearance		],
    [ "height",			Keycap_height			],
    [ "path",			Keycap_path				],
    [ "position",		Keycap_position			],
    [ "profile",		Keycap_profile			],
    [ "styles",			Keycap_styles			],
    [ "testClearance",	Keycap_testClearance	],
    [ "visible",        Keycap_visible          ],
] );

/*******************************************************************************\
|									LEDs										|
\*******************************************************************************/

LED = object ( [
    [ "present",		LED_present		],
    [ "count",			LED_count		],
    [ "holeShape",		LED_holeShape	],
    [ "holeSize",		LED_holeSize	],
    [ "holeSpacing",	LED_holeSpacing	],
    [ "position",		LED_position	],
] );

/*******************************************************************************\
|								Magnetic Connector								|
\*******************************************************************************/

MagCon = object ( [
    [ "color",			MagCon_color		],
    [ "lip",			MagCon_lip			],
    [ "lipOffset",		MagCon_lipOffset	],
    [ "pcbSize",		MagCon_pcbSize		],
    [ "pcbPosition",	MagCon_pcbPosition	],
    [ "position",		MagCon_position		],
    [ "size",			MagCon_size			],
    [ "visible",        MagCon_visible      ],
] );

/*******************************************************************************\
|										MCU										|
\*******************************************************************************/

MCU = object ( [
    [ "chipSize",		MCU_chipSize	],
    [ "pcbColor",		MCU_pcbColor	],
    [ "radius",			MCU_radius		],
    [ "size",			MCU_size		],
    [ "usbOverhang",	MCU_usbOverhang	],
    [ "usbRadius",		MCU_usbRadius	],
    [ "usbSize",		MCU_usbSize		],
    [ "visible",        MCU_visible     ],
] );

/*******************************************************************************\
|										PCBs									|
\*******************************************************************************/

PCB = object ( [
    [ "color",		PCB_color		],
    [ "edge",		PCB_edge		],
    [ "position",	PCB_position	],
    [ "thickness",	PCB_thickness	],
    [ "visible",    PCB_visible     ],
] );

/*******************************************************************************\
|									Plates										|
\*******************************************************************************/
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

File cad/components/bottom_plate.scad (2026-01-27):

/*******************************************************************************\
|						Bottom plate for Androphage keyboard.					|
|							Copyright 2026 Joshua Lucas 						|
\*******************************************************************************/

include <../globals.scad>

use <plate.scad>

use <../library/fillet.scad>
use <../library/screw.scad>

if ( is_undef ( $parent_modules ) ) {
    include <../androphage.scad>

    bottom_plate (
        Frame,
        // Halves,
        Plate,
        // Screw
    );
}

module bottom_plate (
    frame,
    // halves,
    plate,
    // screw,
    // edge		= BottomPlate_edge,
    // outerRadius	= Plate_outerRadius,
    // thickness	= BottomPlate_thickness,
    // zpos		= 0
) {
    linear_extrude ( height = plate.Bottom.thickness ) {
        fillet2d ( radius = plate.outerRadius ) {
            plate_sketch ( frame );
        }
    }

                // Subtract coutersunk screw holes for rendering / CNC milling.
                // place_screws (
                //     thickness	= thickness
                // ) {
                //     screw (
                //         diameter	= screw.diameter,
                //         length		= 2,
                //         head		= "flat",
                //         drive		= "none"
                //     );
                // }
}

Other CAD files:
cad/components/keycaps/Choc_Chicago_Steno_r0.stl
cad/production/case_left.stl
cad/components/case_frame.scad
cad/components/keycaps/Choc_Chicago_Steno_r1.stl
cad/components/keycaps/Choc_Chicago_Steno_r3.stl
cad/components/pcb.scad
cad/components/plate_sketch.scad
cad/components/plates_common.scad
cad/components/top_plate.scad
cad/production/bottom.dxf
cad/production/case_combined.stl
cad/production/pcb.dxf
cad/production/switch.dxf
cad/production/top.dxf

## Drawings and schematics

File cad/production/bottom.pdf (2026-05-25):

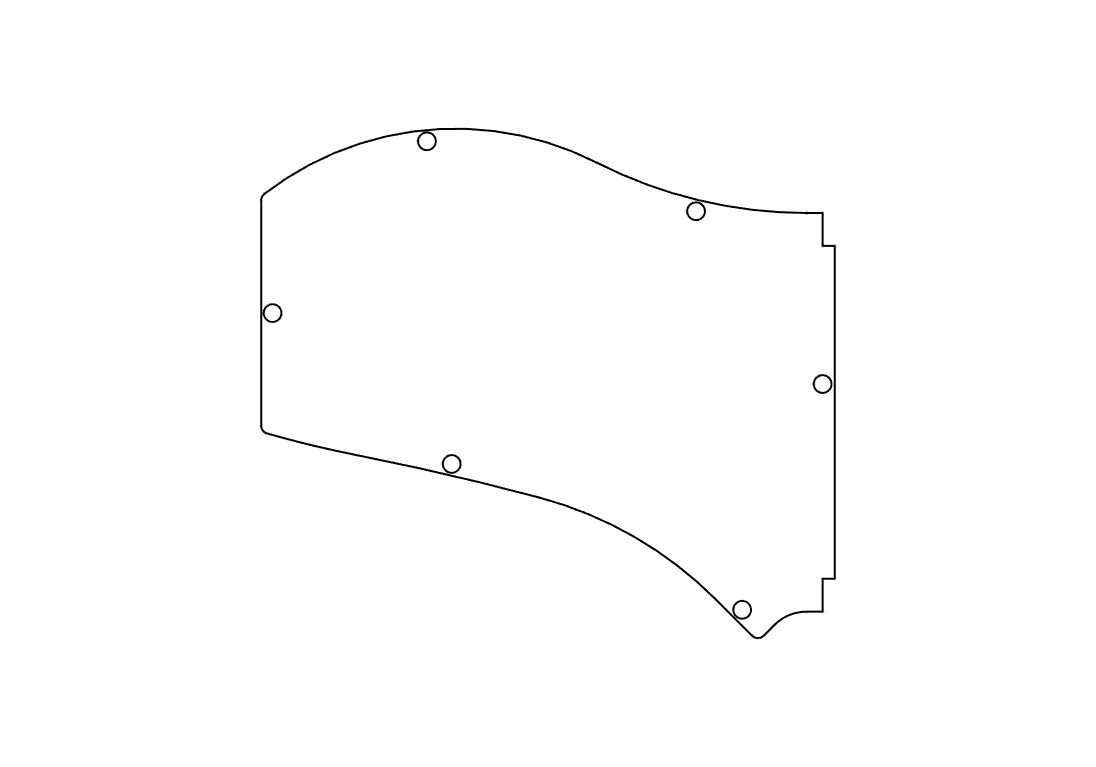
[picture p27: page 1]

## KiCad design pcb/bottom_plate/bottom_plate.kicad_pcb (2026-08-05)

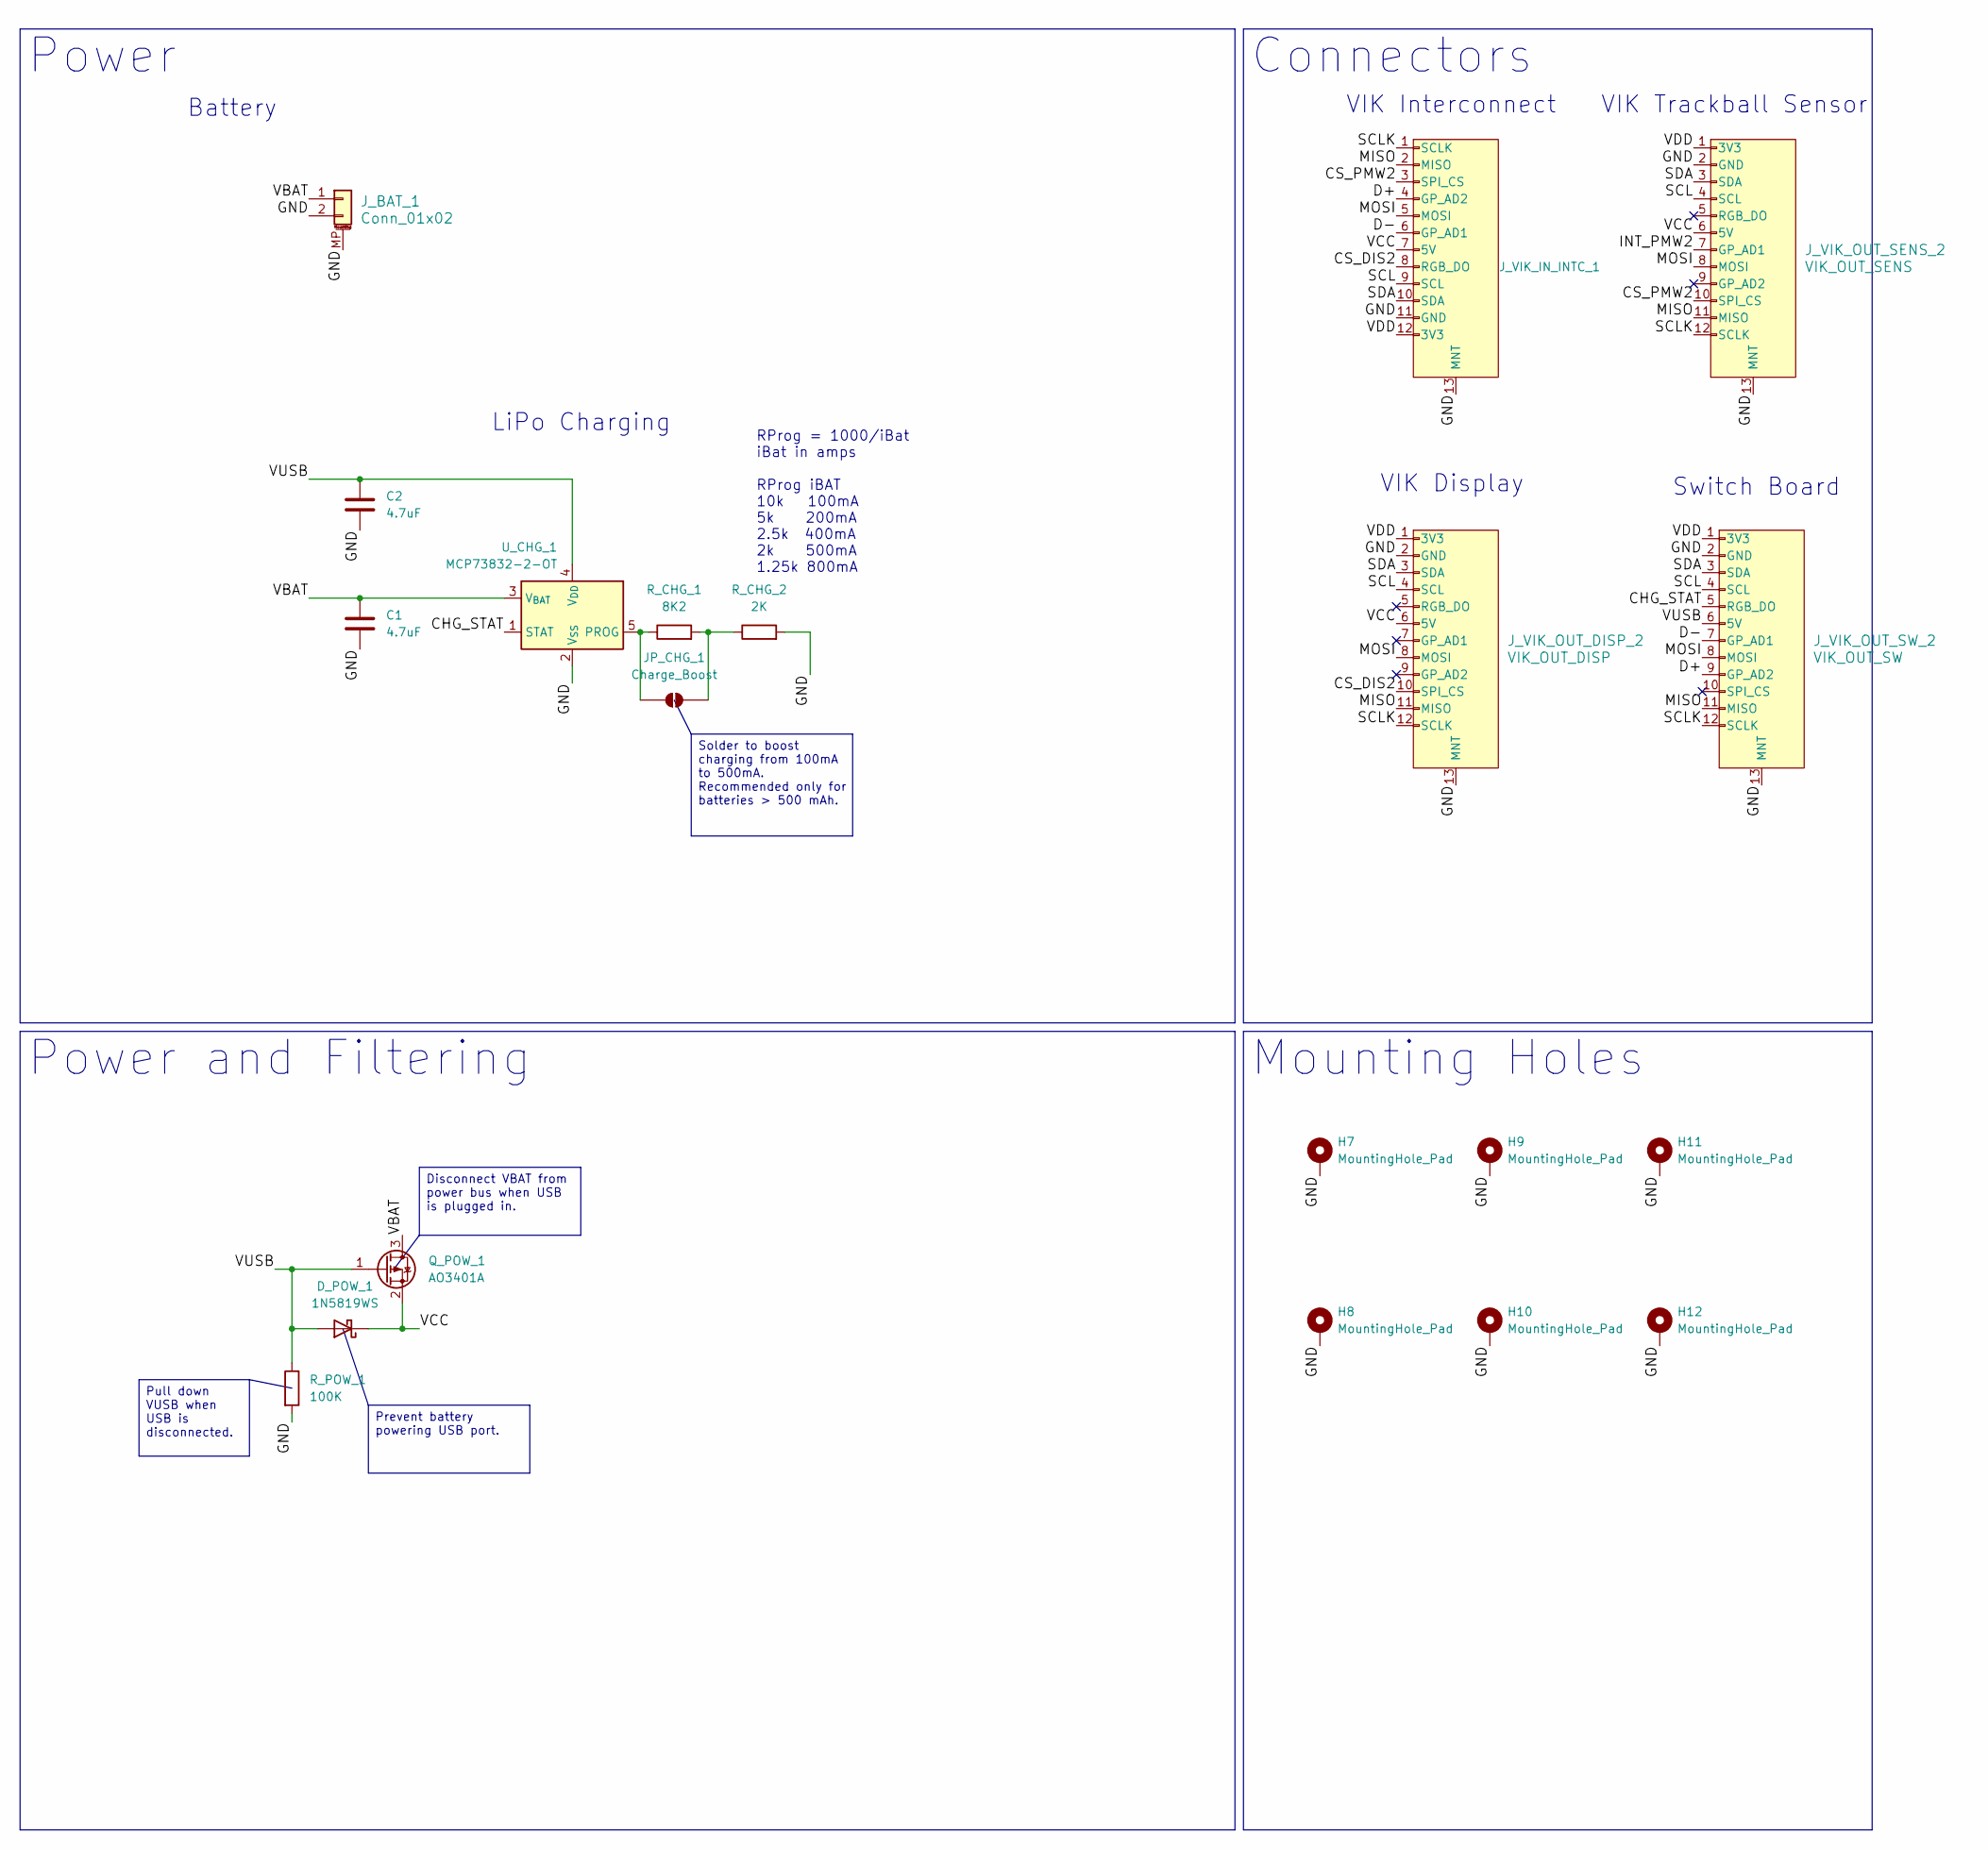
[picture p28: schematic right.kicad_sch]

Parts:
C1, C2: 4.7uF; C_0805_2012Metric_Pad1.18x1.45mm_HandSolder
D_POW_1: 1N5819WS; D_SOD-123
H7, H8, H9, H10, H11, H12: MountingHole_Pad; MountingHole_2.2mm_M2_Pad
JP_CHG_1: Charge_Boost; SolderJumper-2_P1.3mm_Open_RoundedPad1.0x1.5mm
J_BAT_1: Conn_01x02; JST_GH_SM02B-GHS-TB_1x02-1MP_P1.25mm_Horizontal
J_VIK_IN_INTC_1: vik-module-connector; vik-module-connector-horizontal
J_VIK_OUT_DISP_2: VIK_OUT_DISP; vik-keyboard-connector-horizontal
J_VIK_OUT_SENS_2: VIK_OUT_SENS; vik-keyboard-connector-horizontal
J_VIK_OUT_SW_2: VIK_OUT_SW; vik-keyboard-connector-horizontal
Q_POW_1: AO3401A; SOT-23
R_CHG_1: 8K2; R_0805_2012Metric_Pad1.20x1.40mm_HandSolder
R_CHG_2: 2K; R_0805_2012Metric_Pad1.20x1.40mm_HandSolder
R_POW_1: 100K; R_0805_2012Metric_Pad1.20x1.40mm_HandSolder
U_CHG_1: MCP73832-2-OT; SOT-23-5

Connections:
/Right/CHG_STAT: J_VIK_OUT_SW_2.5 (RGB_DO), U_CHG_1.1 (STAT)
/Right/CS_DIS2: J_VIK_IN_INTC_1.8 (RGB_DO), J_VIK_OUT_DISP_2.10 (SPI_CS)
/Right/CS_PMW2: J_VIK_IN_INTC_1.3 (SPI_CS), J_VIK_OUT_SENS_2.10 (SPI_CS)
/Right/D+: J_VIK_IN_INTC_1.4 (GP_AD2), J_VIK_OUT_SW_2.9 (GP_AD2)
/Right/D-: J_VIK_IN_INTC_1.6 (GP_AD1), J_VIK_OUT_SW_2.7 (GP_AD1)
/Right/GND: C1.2, C2.2, H7.1 (1_1), H8.1 (1_1), H9.1 (1_1), H10.1 (1_1), H11.1 (1_1), H12.1 (1_1), J_BAT_1.2, J_BAT_1.MP (MountPin), J_VIK_IN_INTC_1.11 (GND), J_VIK_IN_INTC_1.13 (MNT), J_VIK_OUT_DISP_2.2 (GND), J_VIK_OUT_DISP_2.13 (MNT), J_VIK_OUT_SENS_2.2 (GND), J_VIK_OUT_SENS_2.13 (MNT), J_VIK_OUT_SW_2.2 (GND), J_VIK_OUT_SW_2.13 (MNT), R_CHG_2.2, R_POW_1.2, U_CHG_1.2 (V_{SS})
/Right/INT_PMW2: J_VIK_OUT_SENS_2.7 (GP_AD1)
/Right/MISO: J_VIK_IN_INTC_1.2 (MISO), J_VIK_OUT_DISP_2.11 (MISO), J_VIK_OUT_SENS_2.11 (MISO), J_VIK_OUT_SW_2.11 (MISO)
/Right/MOSI: J_VIK_IN_INTC_1.5 (MOSI), J_VIK_OUT_DISP_2.8 (MOSI), J_VIK_OUT_SENS_2.8 (MOSI), J_VIK_OUT_SW_2.8 (MOSI)
/Right/SCL: J_VIK_IN_INTC_1.9 (SCL), J_VIK_OUT_DISP_2.4 (SCL), J_VIK_OUT_SENS_2.4 (SCL), J_VIK_OUT_SW_2.4 (SCL)
/Right/SCLK: J_VIK_IN_INTC_1.1 (SCLK), J_VIK_OUT_DISP_2.12 (SCLK), J_VIK_OUT_SENS_2.12 (SCLK), J_VIK_OUT_SW_2.12 (SCLK)
/Right/SDA: J_VIK_IN_INTC_1.10 (SDA), J_VIK_OUT_DISP_2.3 (SDA), J_VIK_OUT_SENS_2.3 (SDA), J_VIK_OUT_SW_2.3 (SDA)
/Right/VBAT: C1.1, J_BAT_1.1, Q_POW_1.3 (D), U_CHG_1.3 (V_{BAT})
/Right/VCC: D_POW_1.1 (K), J_VIK_IN_INTC_1.7 (5V), J_VIK_OUT_DISP_2.6 (5V), J_VIK_OUT_SENS_2.6 (5V), Q_POW_1.2 (S)
/Right/VDD: J_VIK_IN_INTC_1.12 (3V3), J_VIK_OUT_DISP_2.1 (3V3), J_VIK_OUT_SENS_2.1 (3V3), J_VIK_OUT_SW_2.1 (3V3)
/Right/VUSB: C2.1, D_POW_1.2 (A), J_VIK_OUT_SW_2.6 (5V), Q_POW_1.1 (G), R_POW_1.1, U_CHG_1.4 (V_{DD})
unnamed: JP_CHG_1.1 (A), R_CHG_1.1, U_CHG_1.5 (PROG)
unnamed: JP_CHG_1.2 (B), R_CHG_1.2, R_CHG_2.1

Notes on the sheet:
LiPo Charging
VIK Trackball Sensor
RProg = 1000/iBat iBat in amps RProg iBAT 10k 100mA 5k 200mA 2.5k 400mA 2k 500mA 1.25k 800mA
Switch Board
Battery
VIK Interconnect
VIK Display
Power
Solder to boost charging from 100mA to 500mA. Recommended only for batteries > 500 mAh.
Mounting Holes
Pull down VUSB when USB is disconnected.
Disconnect VBAT from power bus when USB is plugged in.
Prevent battery powering USB port.
Power and Filtering
Connectors

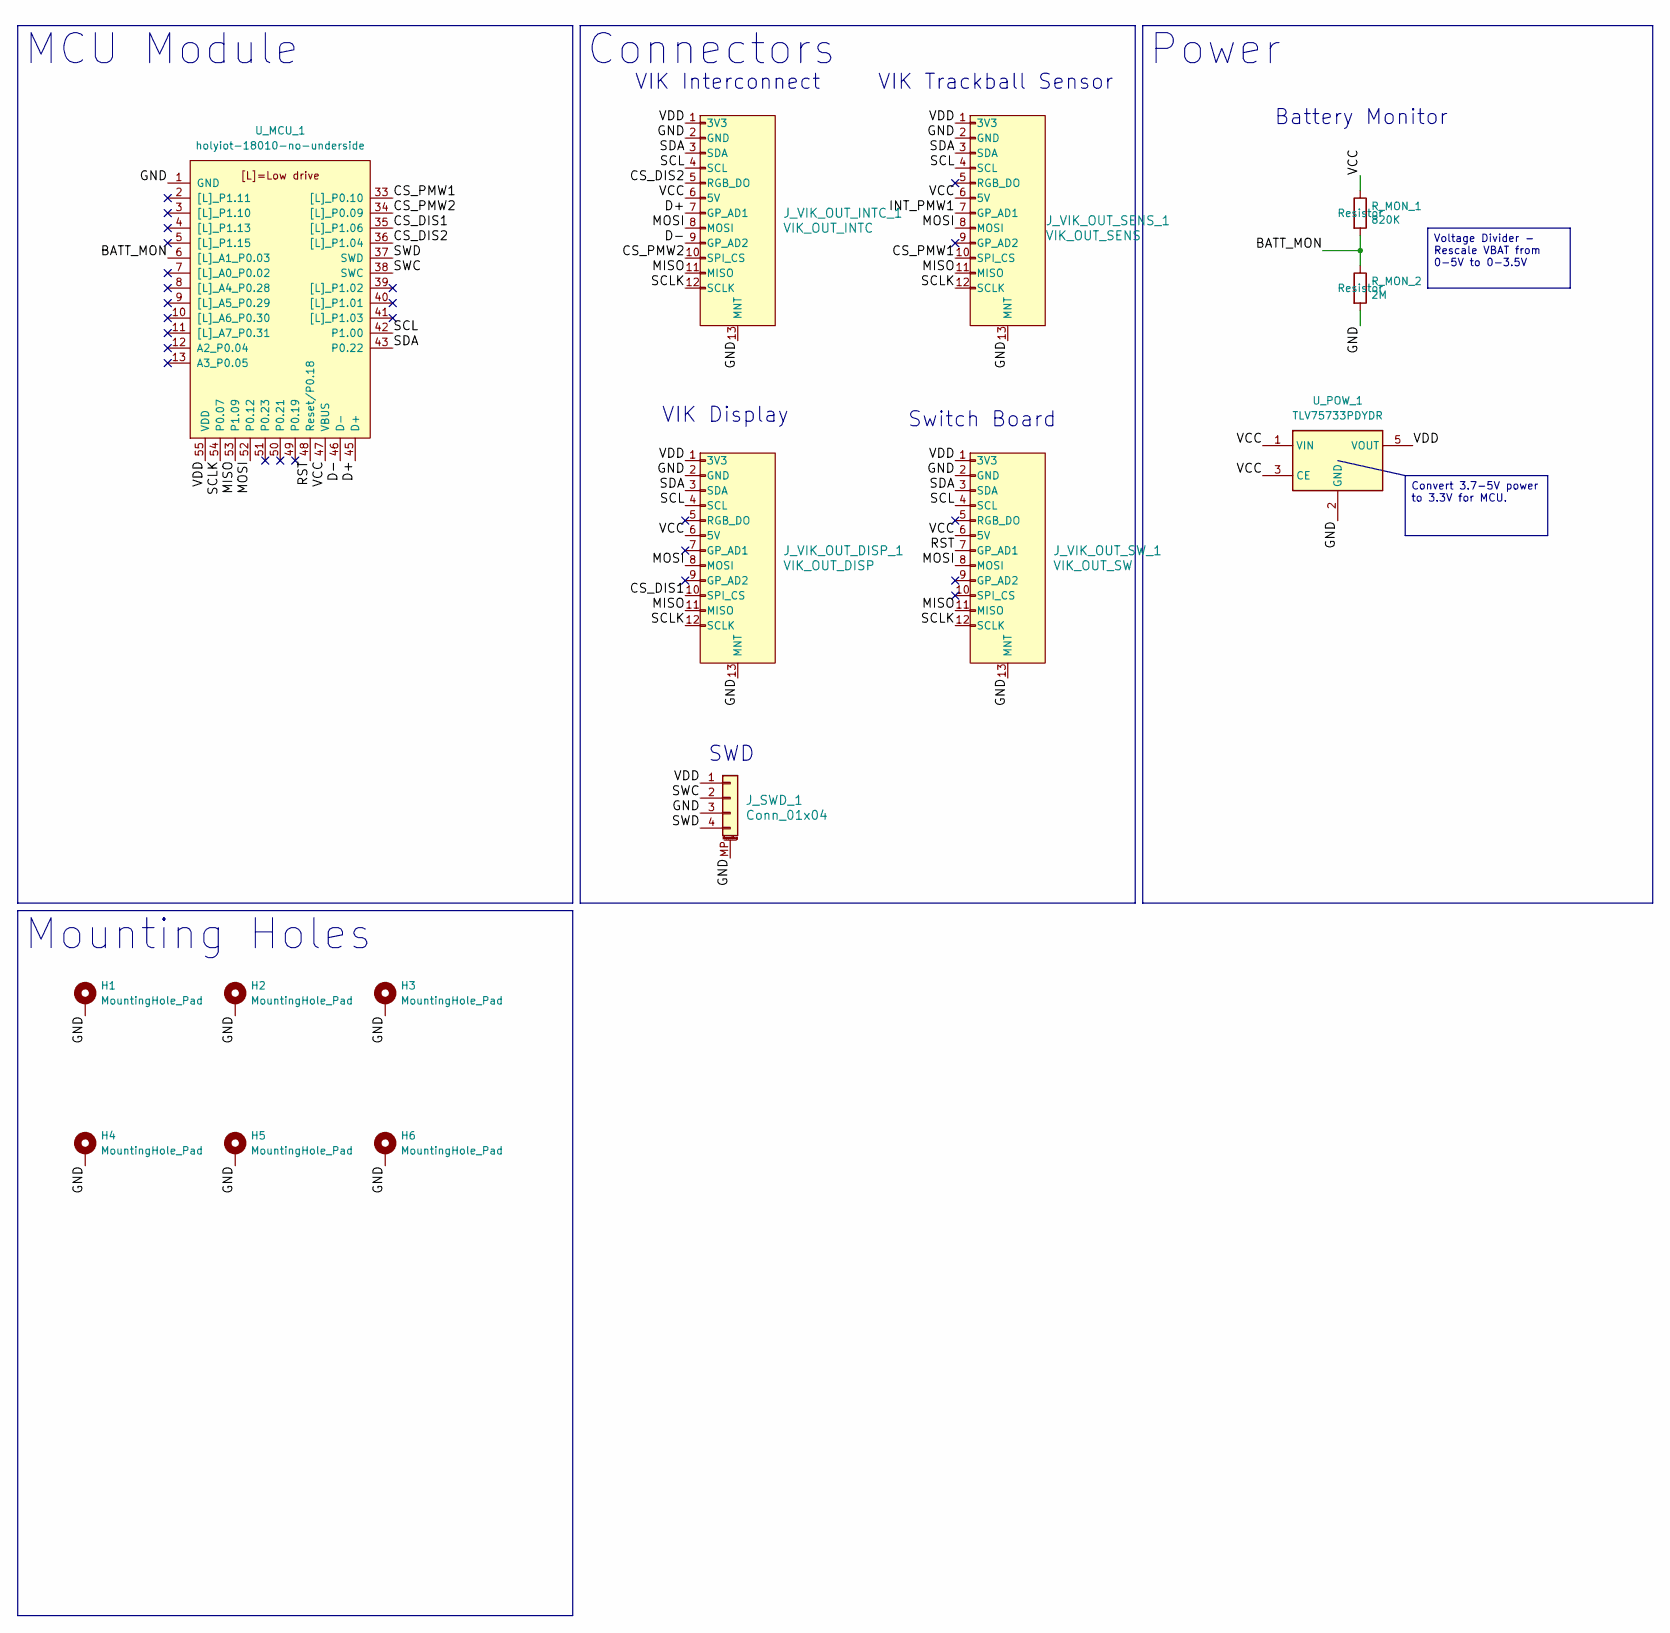
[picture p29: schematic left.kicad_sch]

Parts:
H1, H2, H3, H4, H5, H6: MountingHole_Pad; MountingHole_2.2mm_M2_Pad
J_SWD_1: Conn_01x04; JST_GH_SM04B-GHS-TB_1x04-1MP_P1.25mm_Horizontal
J_VIK_OUT_DISP_1: VIK_OUT_DISP; vik-keyboard-connector-horizontal
J_VIK_OUT_INTC_1: VIK_OUT_INTC; vik-keyboard-connector-horizontal
J_VIK_OUT_SENS_1: VIK_OUT_SENS; vik-keyboard-connector-horizontal
J_VIK_OUT_SW_1: VIK_OUT_SW; vik-keyboard-connector-horizontal
R_MON_1: 820K; R_0805_2012Metric_Pad1.20x1.40mm_HandSolder
R_MON_2: 2M; R_0805_2012Metric_Pad1.20x1.40mm_HandSolder
U_MCU_1: holyiot-18010-no-underside
U_POW_1: TLV75733PDYDR; SOT-23-5; LCSC C22399950

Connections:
/Left/BATT_MON: R_MON_1.2, R_MON_2.1, U_MCU_1.6 ([L]_A1_P0.03)
/Left/CS_DIS1: J_VIK_OUT_DISP_1.10 (SPI_CS), U_MCU_1.35 ([L]_P1.06)
/Left/CS_DIS2: J_VIK_OUT_INTC_1.5 (RGB_DO), U_MCU_1.36 ([L]_P1.04)
/Left/CS_PMW1: J_VIK_OUT_SENS_1.10 (SPI_CS), U_MCU_1.33 ([L]_P0.10)
/Left/CS_PMW2: J_VIK_OUT_INTC_1.10 (SPI_CS), U_MCU_1.34 ([L]_P0.09)
/Left/D+: J_VIK_OUT_INTC_1.7 (GP_AD1), U_MCU_1.45 (D+)
/Left/D-: J_VIK_OUT_INTC_1.9 (GP_AD2), U_MCU_1.46 (D-)
/Left/GND: H1.1 (1_1), H2.1 (1_1), H3.1 (1_1), H4.1 (1_1), H5.1 (1_1), H6.1 (1_1), J_SWD_1.3, J_SWD_1.MP (MountPin), J_VIK_OUT_DISP_1.2 (GND), J_VIK_OUT_DISP_1.13 (MNT), J_VIK_OUT_INTC_1.2 (GND), J_VIK_OUT_INTC_1.13 (MNT), J_VIK_OUT_SENS_1.2 (GND), J_VIK_OUT_SENS_1.13 (MNT), J_VIK_OUT_SW_1.2 (GND), J_VIK_OUT_SW_1.13 (MNT), R_MON_2.2, U_MCU_1.1 (GND), U_MCU_1.32 (GND), U_MCU_1.44 (GND), U_POW_1.2 (GND)
/Left/INT_PMW1: J_VIK_OUT_SENS_1.7 (GP_AD1)
/Left/MISO: J_VIK_OUT_DISP_1.11 (MISO), J_VIK_OUT_INTC_1.11 (MISO), J_VIK_OUT_SENS_1.11 (MISO), J_VIK_OUT_SW_1.11 (MISO), U_MCU_1.53 (P1.09)
/Left/MOSI: J_VIK_OUT_DISP_1.8 (MOSI), J_VIK_OUT_INTC_1.8 (MOSI), J_VIK_OUT_SENS_1.8 (MOSI), J_VIK_OUT_SW_1.8 (MOSI), U_MCU_1.52 (P0.12)
/Left/RST: J_VIK_OUT_SW_1.7 (GP_AD1), U_MCU_1.48 (Reset/P0.18)
/Left/SCL: J_VIK_OUT_DISP_1.4 (SCL), J_VIK_OUT_INTC_1.4 (SCL), J_VIK_OUT_SENS_1.4 (SCL), J_VIK_OUT_SW_1.4 (SCL), U_MCU_1.42 (P1.00)
/Left/SCLK: J_VIK_OUT_DISP_1.12 (SCLK), J_VIK_OUT_INTC_1.12 (SCLK), J_VIK_OUT_SENS_1.12 (SCLK), J_VIK_OUT_SW_1.12 (SCLK), U_MCU_1.54 (P0.07)
/Left/SDA: J_VIK_OUT_DISP_1.3 (SDA), J_VIK_OUT_INTC_1.3 (SDA), J_VIK_OUT_SENS_1.3 (SDA), J_VIK_OUT_SW_1.3 (SDA), U_MCU_1.43 (P0.22)
/Left/SWC: J_SWD_1.2, U_MCU_1.38 (SWC)
/Left/SWD: J_SWD_1.4, U_MCU_1.37 (SWD)
/Left/VCC: J_VIK_OUT_DISP_1.6 (5V), J_VIK_OUT_INTC_1.6 (5V), J_VIK_OUT_SENS_1.6 (5V), J_VIK_OUT_SW_1.6 (5V), R_MON_1.1, U_MCU_1.47 (VBUS), U_POW_1.1 (VIN), U_POW_1.3 (CE)
/Left/VDD: J_SWD_1.1, J_VIK_OUT_DISP_1.1 (3V3), J_VIK_OUT_INTC_1.1 (3V3), J_VIK_OUT_SENS_1.1 (3V3), J_VIK_OUT_SW_1.1 (3V3), U_MCU_1.55 (VDD), U_POW_1.5 (VOUT)

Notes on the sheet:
Switch Board
VIK Trackball Sensor
Battery Monitor
SWD
VIK Display
VIK Interconnect
Voltage Divider - Rescale VBAT from 0-5V to 0-3.5V
Convert 3.7-5V power to 3.3V for MCU.
MCU Module
Connectors
Mounting Holes
Power

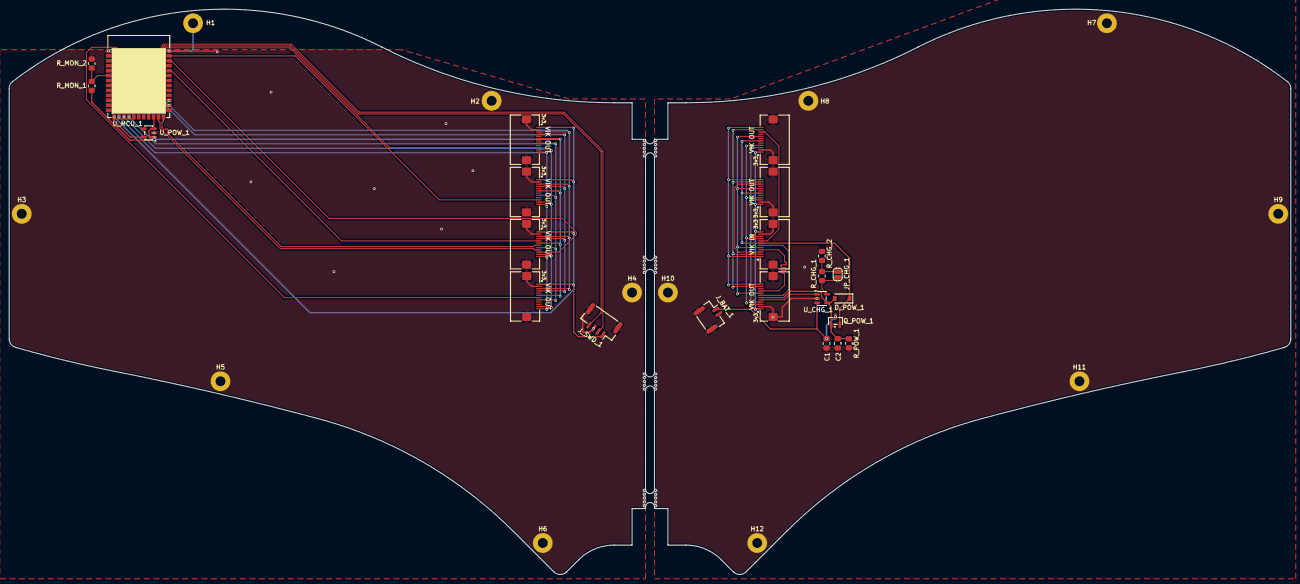
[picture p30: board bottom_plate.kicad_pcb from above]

Board: 2 copper layers, 285.8 x 126.1 mm, 35 parts (0 on the bottom side), 35 nets.

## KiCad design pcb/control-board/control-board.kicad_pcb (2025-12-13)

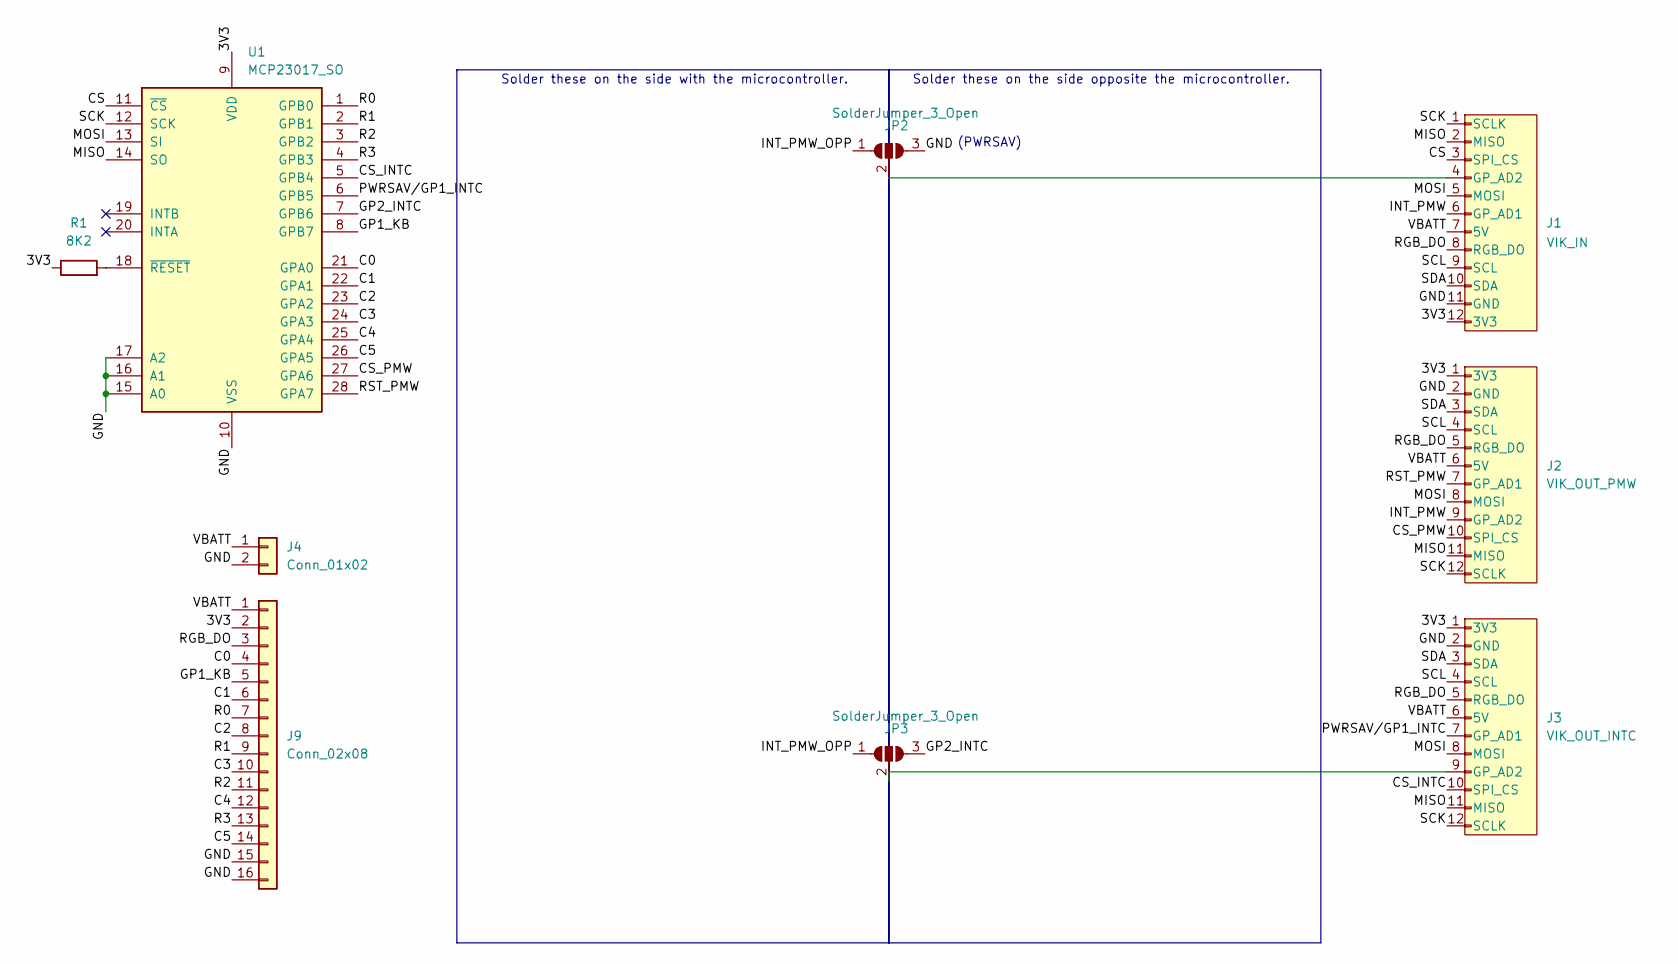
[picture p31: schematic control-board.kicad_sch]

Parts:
J1: VIK_IN; vik-module-connector-horizontal
J2: VIK_OUT_PMW; vik-keyboard-connector-horizontal
J3: VIK_OUT_INTC; vik-keyboard-connector-horizontal
J4: Conn_01x02; JST_PH_S2B-PH-K_1x02_P2.00mm_Horizontal
J9: Conn_02x08; PinHeader_2x08_P2.54mm_Vertical
JP2, JP3: SolderJumper_3_Open; SolderJumper-3_P1.3mm_Open_RoundedPad1.0x1.5mm
R1: 8K2; R_0805_2012Metric_Pad1.20x1.40mm_HandSolder
U1: MCP23017_SO; SOIC-28W_7.5x17.9mm_P1.27mm

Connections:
/3V3: J1.12 (3V3), J2.1 (3V3), J3.1 (3V3), J9.2, R1.1, U1.9 (VDD)
/C0: J9.4, U1.21 (GPA0)
/C1: J9.6, U1.22 (GPA1)
/C2: J9.8, U1.23 (GPA2)
/C3: J9.10, U1.24 (GPA3)
/C4: J9.12, U1.25 (GPA4)
/C5: J9.14, U1.26 (GPA5)
/CS: J1.3 (SPI_CS), U1.11 (~CS)
/CS_INTC: J3.10 (SPI_CS), U1.5 (GPB4)
/CS_PMW: J2.10 (SPI_CS), U1.27 (GPA6)
/GND: J1.11 (GND), J2.2 (GND), J3.2 (GND), J4.2, J9.15, J9.16, JP2.3 (B), U1.10 (VSS), U1.15 (A0), U1.16 (A1), U1.17 (A2)
/GP1_KB: J9.5, U1.8 (GPB7)
/GP2_INTC: JP3.3 (B), U1.7 (GPB6)
/INT_PMW: J1.6 (GP_AD1), J2.9 (GP_AD2)
/INT_PMW_OPP: JP2.1 (A), JP3.1 (A)
/MISO: J1.2 (MISO), J2.11 (MISO), J3.11 (MISO), U1.14 (SO)
/MOSI: J1.5 (MOSI), J2.8 (MOSI), J3.8 (MOSI), U1.13 (SI)
/PWRSAV/GP1_INTC: J3.7 (GP_AD1), U1.6 (GPB5)
/R0: J9.7, U1.1 (GPB0)
/R1: J9.9, U1.2 (GPB1)
/R2: J9.11, U1.3 (GPB2)
/R3: J9.13, U1.4 (GPB3)
/RGB_DO: J1.8 (RGB_DO), J2.5 (RGB_DO), J3.5 (RGB_DO), J9.3
/RST_PMW: J2.7 (GP_AD1), U1.28 (GPA7)
/SCK: J1.1 (SCLK), J2.12 (SCLK), J3.12 (SCLK), U1.12 (SCK)
/SCL: J1.9 (SCL), J2.4 (SCL), J3.4 (SCL)
/SDA: J1.10 (SDA), J2.3 (SDA), J3.3 (SDA)
/VBATT: J1.7 (5V), J2.6 (5V), J3.6 (5V), J4.1, J9.1
unnamed: J1.4 (GP_AD2), JP2.2 (C)
unnamed: J3.9 (GP_AD2), JP3.2 (C)
unnamed: R1.2, U1.18 (~RESET)

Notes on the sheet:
Solder these on the side opposite the microcontroller.
Solder these on the side with the microcontroller.
(PWRSAV)

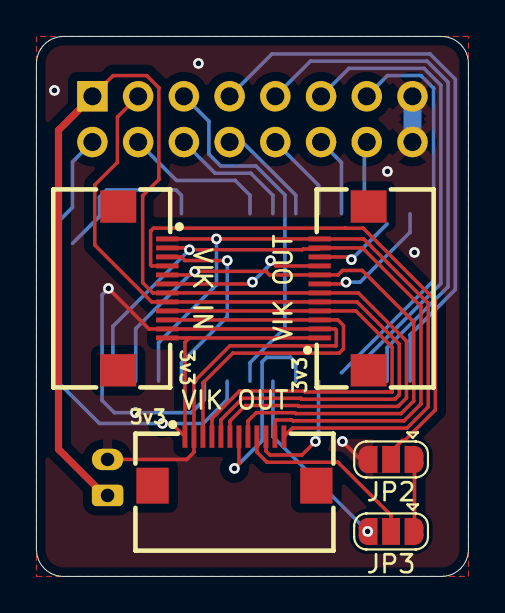
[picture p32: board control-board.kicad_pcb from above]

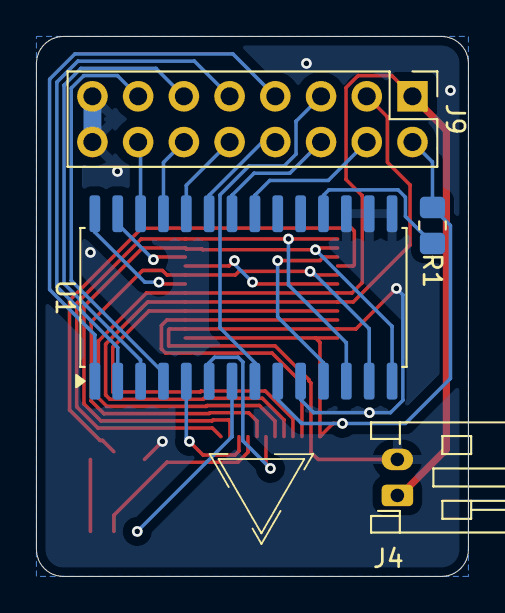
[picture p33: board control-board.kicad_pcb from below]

Board: 2 copper layers, 24.0 x 30.0 mm, 9 parts (4 on the bottom side), 31 nets.

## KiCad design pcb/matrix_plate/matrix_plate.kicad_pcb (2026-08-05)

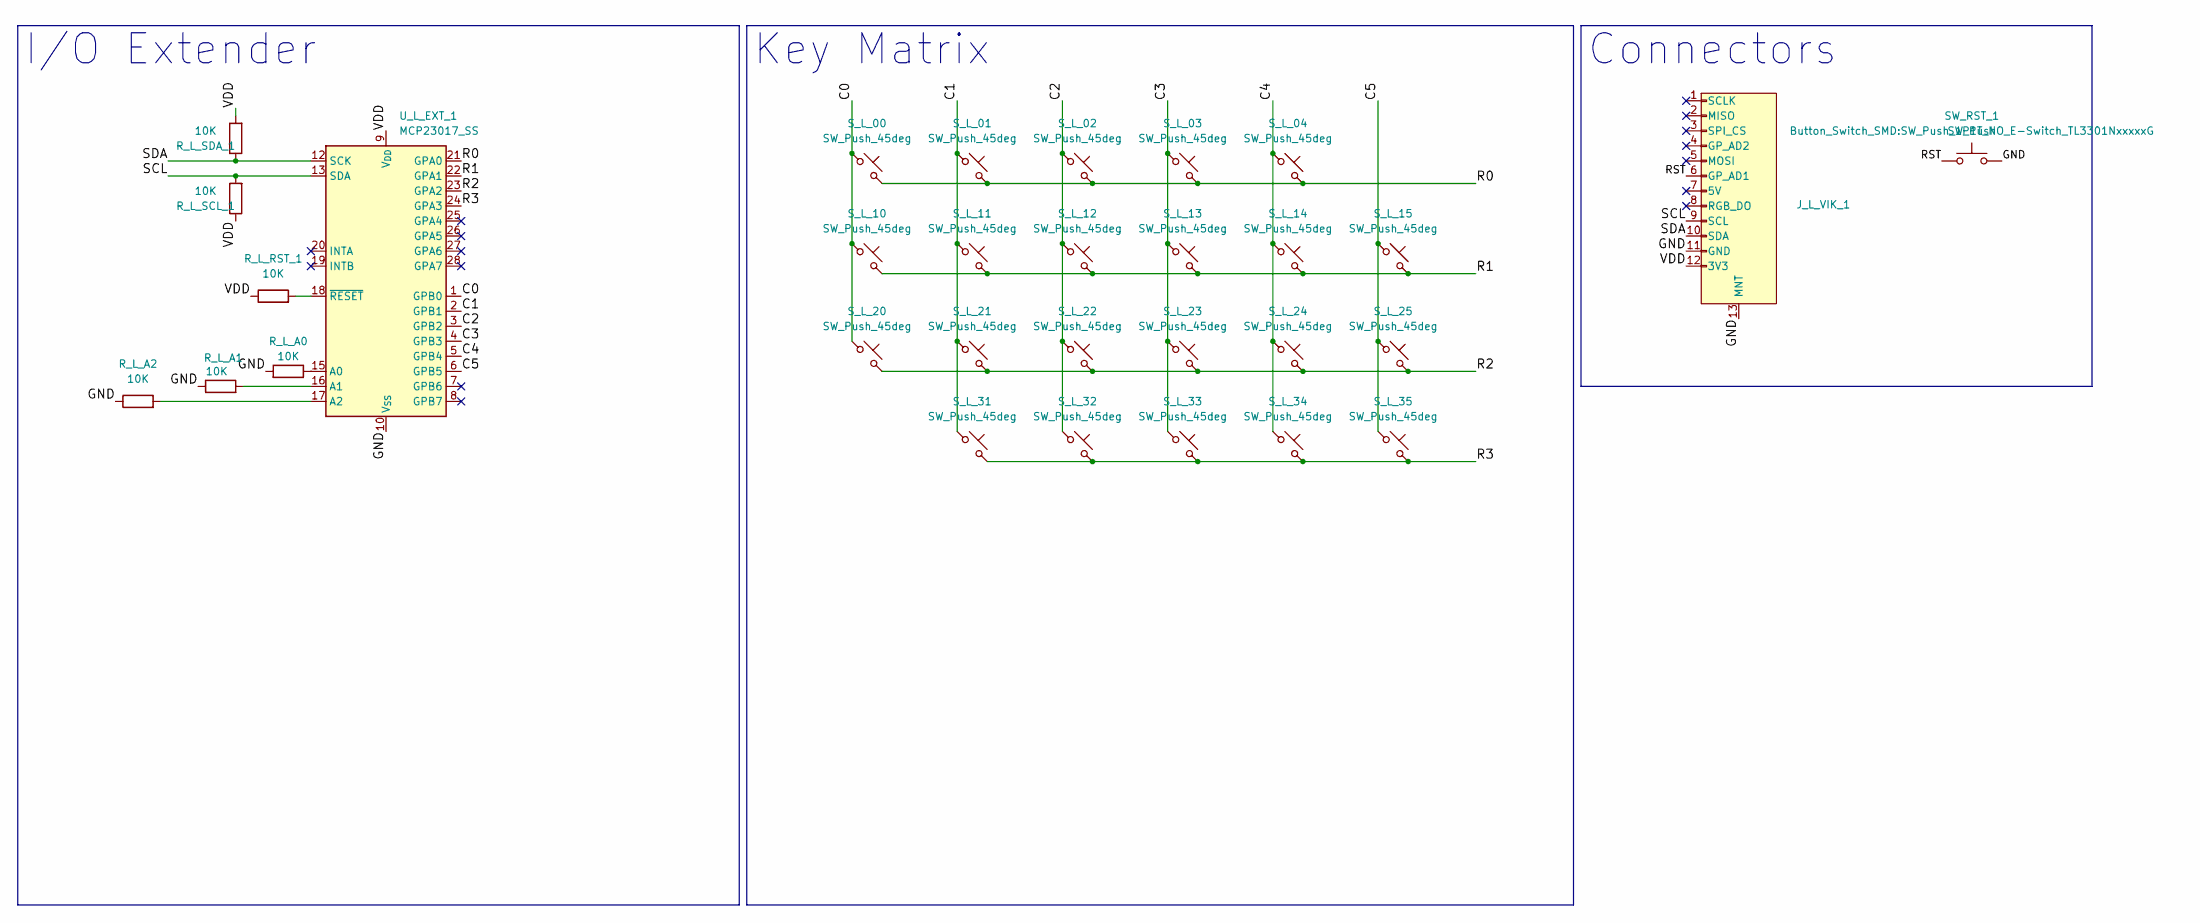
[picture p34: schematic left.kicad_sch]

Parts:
J_L_VIK_1: vik-module-connector; vik-module-connector-horizontal
R_L_A0, R_L_A1, R_L_A2: 10K; R_0805_2012Metric_Pad1.20x1.40mm_HandSolder
R_L_RST_1: 10K; R_0805_2012Metric_Pad1.20x1.40mm_HandSolder
R_L_SCL_1: 10K; R_0805_2012Metric_Pad1.20x1.40mm_HandSolder
R_L_SDA_1: 10K; R_0805_2012Metric_Pad1.20x1.40mm_HandSolder
SW_RST_1: SW_Push; SW_Push_1P1T_NO_E-Switch_TL3301NxxxxxG
S_L_00, S_L_01, S_L_02, S_L_03, S_L_04, S_L_10, S_L_11, S_L_12, S_L_13, S_L_14, S_L_15, S_L_20, S_L_21, S_L_22, S_L_23, S_L_24, S_L_25, S_L_31, S_L_32, S_L_33, S_L_34, S_L_35: SW_Push_45deg; SW_GLP_Kailh_Choc_V1V2_HotSwap_PTH
U_L_EXT_1: MCP23017_SS; SSOP-28_5.3x10.2mm_P0.65mm

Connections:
/Left/C0: S_L_00.1, S_L_10.1, S_L_20.1, U_L_EXT_1.1 (GPB0)
/Left/C1: S_L_01.1, S_L_11.1, S_L_21.1, S_L_31.1, U_L_EXT_1.2 (GPB1)
/Left/C2: S_L_02.1, S_L_12.1, S_L_22.1, S_L_32.1, U_L_EXT_1.3 (GPB2)
/Left/C3: S_L_03.1, S_L_13.1, S_L_23.1, S_L_33.1, U_L_EXT_1.4 (GPB3)
/Left/C4: S_L_04.1, S_L_14.1, S_L_24.1, S_L_34.1, U_L_EXT_1.5 (GPB4)
/Left/C5: S_L_15.1, S_L_25.1, S_L_35.1, U_L_EXT_1.6 (GPB5)
/Left/GND: J_L_VIK_1.11 (GND), J_L_VIK_1.13 (MNT), R_L_A0.2, R_L_A1.1, R_L_A2.1, SW_RST_1.2, U_L_EXT_1.10 (V_{SS})
/Left/R0: S_L_00.2, S_L_01.2, S_L_02.2, S_L_03.2, S_L_04.2, U_L_EXT_1.21 (GPA0)
/Left/R1: S_L_10.2, S_L_11.2, S_L_12.2, S_L_13.2, S_L_14.2, S_L_15.2, U_L_EXT_1.22 (GPA1)
/Left/R2: S_L_20.2, S_L_21.2, S_L_22.2, S_L_23.2, S_L_24.2, S_L_25.2, U_L_EXT_1.23 (GPA2)
/Left/R3: S_L_31.2, S_L_32.2, S_L_33.2, S_L_34.2, S_L_35.2, U_L_EXT_1.24 (GPA3)
/Left/RST: J_L_VIK_1.6 (GP_AD1), SW_RST_1.1
/Left/SCL: J_L_VIK_1.9 (SCL), R_L_SCL_1.2, U_L_EXT_1.13 (SDA)
/Left/SDA: J_L_VIK_1.10 (SDA), R_L_SDA_1.1, U_L_EXT_1.12 (SCK)
/Left/VDD: J_L_VIK_1.12 (3V3), R_L_RST_1.1, R_L_SCL_1.1, R_L_SDA_1.2, U_L_EXT_1.9 (V_{DD})
unnamed: R_L_A0.1, U_L_EXT_1.15 (A0)
unnamed: R_L_A1.2, U_L_EXT_1.16 (A1)
unnamed: R_L_A2.2, U_L_EXT_1.17 (A2)
unnamed: R_L_RST_1.2, U_L_EXT_1.18 (~RESET)

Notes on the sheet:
Connectors
Key Matrix
I/O Extender

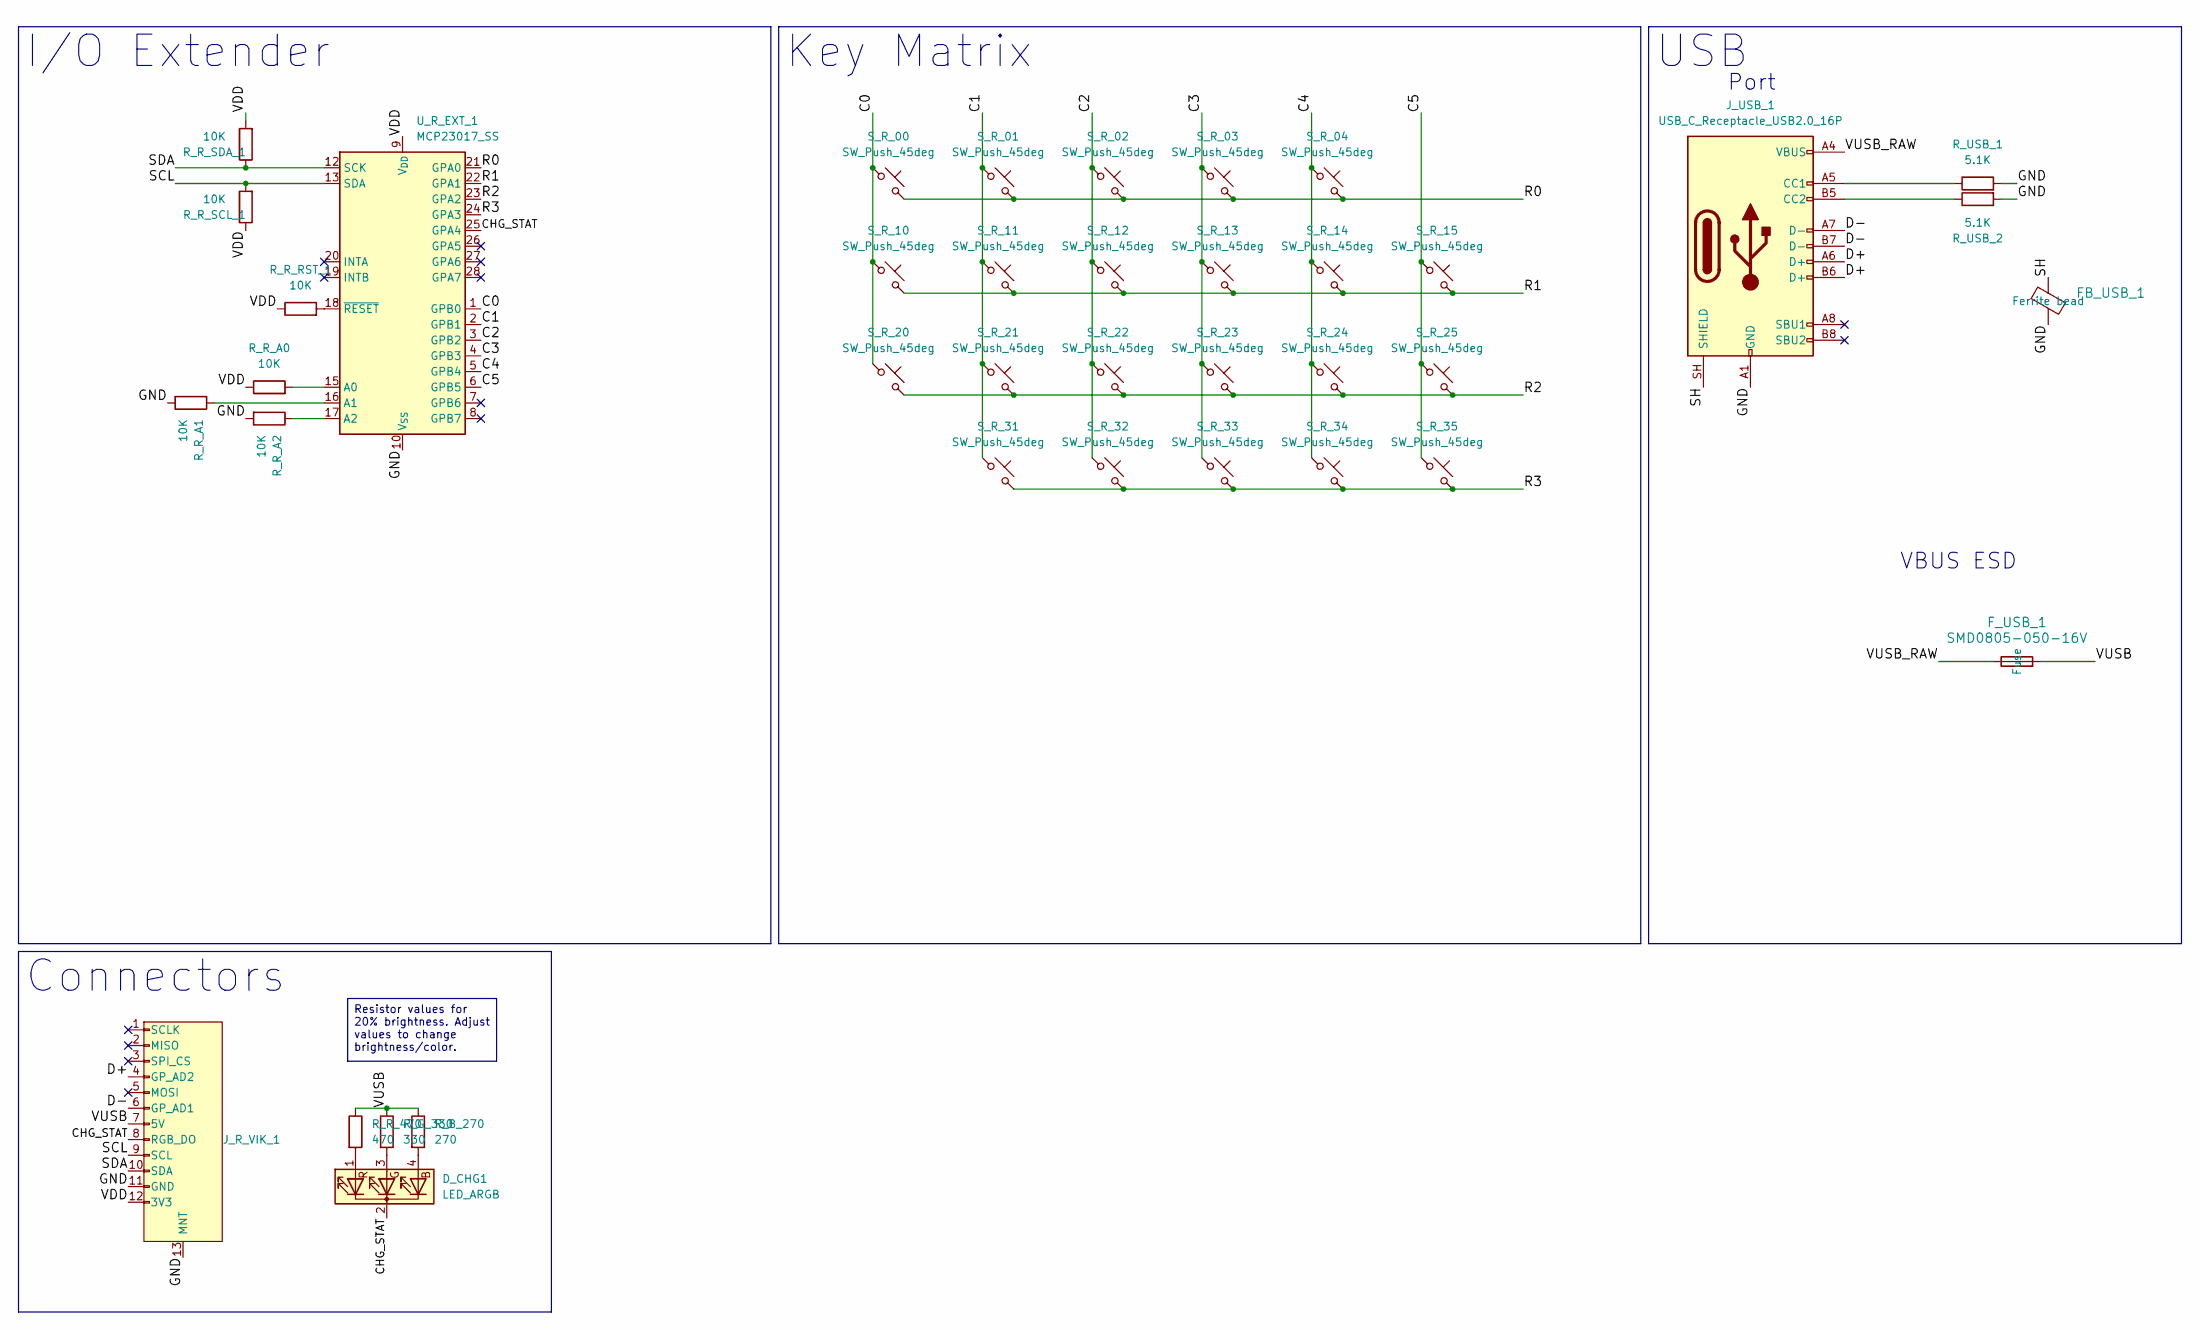
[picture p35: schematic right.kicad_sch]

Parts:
D_CHG1: LED_ARGB; LED_Kingbright_APFA3010_3x1.5mm_Horizontal
FB_USB_1: L_0805_2012Metric_Pad1.05x1.20mm_HandSolder; LCSC Part Number C21286
F_USB_1: SMD0805-050-16V; Fuse_0805_2012Metric_Pad1.15x1.40mm_HandSolder; Manufacturer Part Number SMD0805-050-16V; LCSC Part Number C2833485
J_R_VIK_1: vik-module-connector; vik-module-connector-horizontal
J_USB_1: USB_C_Receptacle_USB2.0_16P; USB_C_Receptacle_HRO_TYPE-C-31-M-12
R_B_270: 270; R_0805_2012Metric_Pad1.20x1.40mm_HandSolder
R_G_330: 330; R_0805_2012Metric_Pad1.20x1.40mm_HandSolder
R_R_470: 470; R_0805_2012Metric_Pad1.20x1.40mm_HandSolder
R_R_A0, R_R_A1, R_R_A2: 10K; R_0805_2012Metric_Pad1.20x1.40mm_HandSolder
R_R_RST_1: 10K; R_0805_2012Metric_Pad1.20x1.40mm_HandSolder
R_R_SCL_1: 10K; R_0805_2012Metric_Pad1.20x1.40mm_HandSolder
R_R_SDA_1: 10K; R_0805_2012Metric_Pad1.20x1.40mm_HandSolder
R_USB_1, R_USB_2: 5.1K; R_0805_2012Metric_Pad1.20x1.40mm_HandSolder
S_R_00, S_R_01, S_R_02, S_R_03, S_R_04, S_R_10, S_R_11, S_R_12, S_R_13, S_R_14, S_R_15, S_R_20, S_R_21, S_R_22, S_R_23, S_R_24, S_R_25, S_R_31, S_R_32, S_R_33, S_R_34, S_R_35: SW_Push_45deg; SW_GLP_Kailh_Choc_V1V2_HotSwap_PTH
U_R_EXT_1: MCP23017_SS; SSOP-28_5.3x10.2mm_P0.65mm

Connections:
/Right/C0: S_R_00.1, S_R_10.1, S_R_20.1, U_R_EXT_1.1 (GPB0)
/Right/C1: S_R_01.1, S_R_11.1, S_R_21.1, S_R_31.1, U_R_EXT_1.2 (GPB1)
/Right/C2: S_R_02.1, S_R_12.1, S_R_22.1, S_R_32.1, U_R_EXT_1.3 (GPB2)
/Right/C3: S_R_03.1, S_R_13.1, S_R_23.1, S_R_33.1, U_R_EXT_1.4 (GPB3)
/Right/C4: S_R_04.1, S_R_14.1, S_R_24.1, S_R_34.1, U_R_EXT_1.5 (GPB4)
/Right/C5: S_R_15.1, S_R_25.1, S_R_35.1, U_R_EXT_1.6 (GPB5)
/Right/CHG_STAT: D_CHG1.2 (K), J_R_VIK_1.8 (RGB_DO), U_R_EXT_1.25 (GPA4)
/Right/D+: J_R_VIK_1.4 (GP_AD2), J_USB_1.A6 (D+), J_USB_1.B6 (D+)
/Right/D-: J_R_VIK_1.6 (GP_AD1), J_USB_1.A7 (D-), J_USB_1.B7 (D-)
/Right/GND: FB_USB_1.2, J_R_VIK_1.11 (GND), J_R_VIK_1.13 (MNT), J_USB_1.A1 (GND), J_USB_1.A12 (GND), J_USB_1.B1 (GND), J_USB_1.B12 (GND), R_R_A1.2, R_R_A2.2, R_USB_1.2, R_USB_2.2, U_R_EXT_1.10 (V_{SS})
/Right/R0: S_R_00.2, S_R_01.2, S_R_02.2, S_R_03.2, S_R_04.2, U_R_EXT_1.21 (GPA0)
/Right/R1: S_R_10.2, S_R_11.2, S_R_12.2, S_R_13.2, S_R_14.2, S_R_15.2, U_R_EXT_1.22 (GPA1)
/Right/R2: S_R_20.2, S_R_21.2, S_R_22.2, S_R_23.2, S_R_24.2, S_R_25.2, U_R_EXT_1.23 (GPA2)
/Right/R3: S_R_31.2, S_R_32.2, S_R_33.2, S_R_34.2, S_R_35.2, U_R_EXT_1.24 (GPA3)
/Right/SCL: J_R_VIK_1.9 (SCL), R_R_SCL_1.2, U_R_EXT_1.13 (SDA)
/Right/SDA: J_R_VIK_1.10 (SDA), R_R_SDA_1.1, U_R_EXT_1.12 (SCK)
/Right/SH: FB_USB_1.1, J_USB_1.SH (SHIELD)
/Right/VDD: J_R_VIK_1.12 (3V3), R_R_A0.1, R_R_RST_1.1, R_R_SCL_1.1, R_R_SDA_1.2, U_R_EXT_1.9 (V_{DD})
/Right/VUSB: F_USB_1.2, J_R_VIK_1.7 (5V), R_B_270.1, R_G_330.1, R_R_470.1
/Right/VUSB_RAW: F_USB_1.1, J_USB_1.A4 (VBUS), J_USB_1.A9 (VBUS), J_USB_1.B4 (VBUS), J_USB_1.B9 (VBUS)
unnamed: D_CHG1.4 (BA), R_B_270.2
unnamed: D_CHG1.3 (GA), R_G_330.2
unnamed: D_CHG1.1 (RA), R_R_470.2
unnamed: J_USB_1.A5 (CC1), R_USB_1.1
unnamed: J_USB_1.B5 (CC2), R_USB_2.1
unnamed: R_R_A0.2, U_R_EXT_1.15 (A0)
unnamed: R_R_A1.1, U_R_EXT_1.16 (A1)
unnamed: R_R_A2.1, U_R_EXT_1.17 (A2)
unnamed: R_R_RST_1.2, U_R_EXT_1.18 (~RESET)

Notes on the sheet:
VBUS ESD
Port
Connectors
USB
I/O Extender
Key Matrix
Resistor values for 20% brightness. Adjust values to change brightness/color.

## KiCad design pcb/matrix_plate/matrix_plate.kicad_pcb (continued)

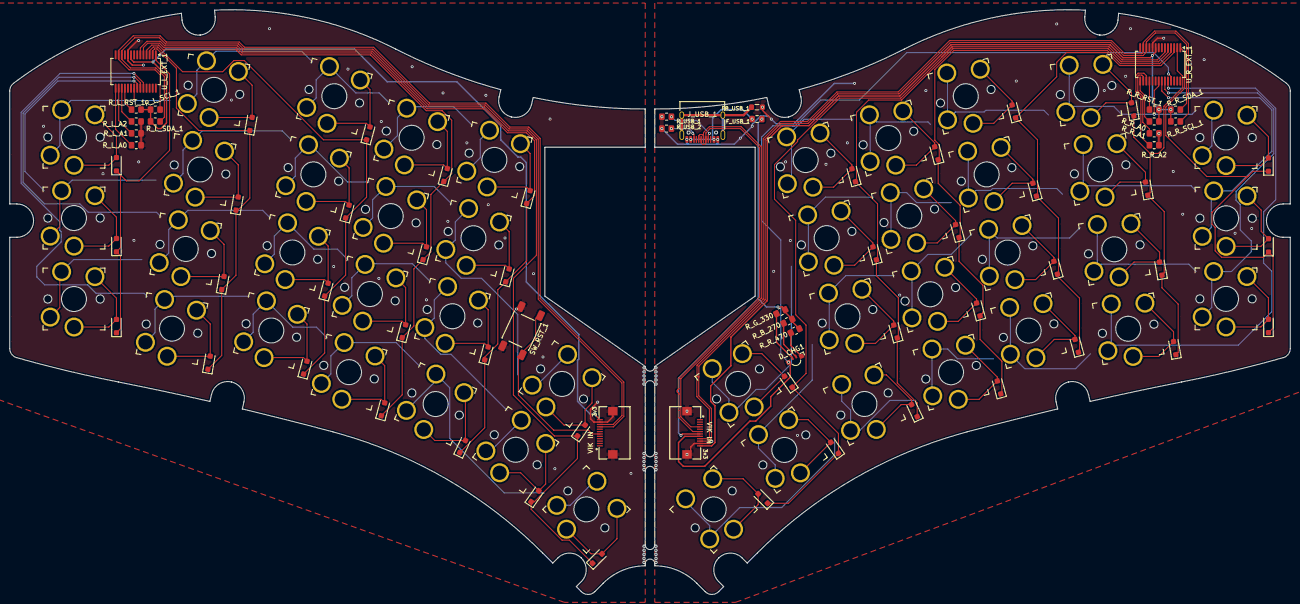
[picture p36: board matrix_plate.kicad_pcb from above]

Board: 2 copper layers, 269.2 x 122.9 mm, 70 parts (0 on the bottom side), 48 nets.

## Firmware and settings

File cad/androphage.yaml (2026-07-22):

# Lengths are in millimeters and angles in degrees unless otherwise noted.

#-------------------------------------#
#         General Parameters          #
#-------------------------------------#

main_half: 1 # 1 = Left, 2 = Right
tent_angle: 10
center_width: 7
pcb_thickness: &pcb_thickness 1.6
pivot_depth: 80
Print:
  # Angle for overhangs on 3d-printed parts.
  overhang_angle: 45
  # Default thickness for 3d-printed parts.
  wall_thickness: &wall_thickness 2
  min_wall_thickness: &min_wall_thickness 1
Columns:
# Spread and Stagger are measured in key spacing units (u).
  # Thumb columns
  reach:
    cutout: true
    splay: -45
    spread: 0.5
    stagger: 0.5
  home:
    connect: 1
    cutout: true
    keys: 2
    splay: 10
  tuck:
    connect: 1
    cutout: true
    splay: 10
  # Finger columns
  inner:
    connect: 1
    cutout: true
    keys: 3
    shift: [1, 1]
    splay: 10
    spread: 1
  index:
    cutout: true
    keys: 4
    spread: 0
  middle:
    keys: 4
    stagger: 0.25
  ring:
    keys: 4
    shift: [0, -0.25]
    splay: 5
    spread: 1.111 # 20 mm
  pinky:
    keys: 3
    splay: 10
    spread: 1.111 # 20 mm
  outer:
    skip: true
    keys: 2
    stagger: 0.75

#-------------------------------------#
#         Option Definitions          #
#-------------------------------------#

# ---- Color Definitions ----
colors:
  black: &black [0x202020, 1]
  brass: &brass [DarkGoldenrod, 1]
  clear: &clear [White, 0.3]
  purple: &purple [MediumPurple, 1]
  silver: &silver [Silver, 1]
  smoke: &smoke [Black, 0.5]
  steel: &steel [DarkGray, 1]
  # Note: CSS 'DarkGray' is more of a light-medium gray.
  pcb_color: &pcb_color [0x202020, 1]

# ---- BTU Options ----
BTU_Options:
  Rexroth: &Rexroth
    visible: true
    adjust_screw: false
    ball_diameter: 7.938
    ball_height: 1.6
    clearance: 10
    collar_height: 1.3
    color: *steel
    flange_diameter: 17
    flange_height: 1.9
    housing_diameter: 12.6
    housing_height: 6.4
    model: Rexroth
  VCN310: &VCN310
    visible: true
    adjust_screw: false
    ball_diameter: 4
    ball_height: 1.1
    clearance: 10
    color: *steel
    flange_diameter: 9
    flange_height: 1
    housing_diameter: 7.5
    housing_height: 4
    model: VCN310
  VCN319: &VCN319
    visible: true
    adjust_screw: false
    ball_diameter: 4.76
    ball_height: 1.2
    clearance: 10
    color: *steel
    drive_width: 5
    drive_depth: 6
    flange_diameter: 7
    flange_height: 0
    housing_diameter: 7
    housing_height: 14.8
    model: VCN319

# ---- Keycap Options ----
Keycap_Profile_Options:
  # Options and heights are from 3dKeycap.com's keycap models.
  Cherry: &Cherry
    height: 10
  Chicago_Steno: &Chicago_Steno # Recommended
    height: 8.5
  DES: &DES # Not recommended
    height: 17
  DSA: &DSA
    height: 8
  FMX: &FMX
    height: 6.3
  funkmonk: &funkmonk
    height: 6
  JWA: &JWA
    height: 6.7
  KEA: &KEA
    height: 5.7
  Lame: &Lame
    height: 10
  SCS: &SCS
    height: 5.5
  sqdg: &sqdg
    height: 7
  XDA: &XDA
    height: 9.5

Keycap_Spacing_Options:
  Choc: &Choc [18, 17]
  MX: &MX_Metric [19, 19]
  MX_Inch: &MX_Inch [19.05, 19.05]

# ---- Screw Options ----
Screws:
  M2: &M2
    visible: true
    color: *steel
    counter_sink_diameter: 4.4
    diameter: 2
    drive_depth: 1
    drive_width: 1.3
    head_diameter: 4
    head_angle: 90
    hole_diameter: 2.4
    minor_diameter: 1.6
  M3: &M3
    visible: true
    color: *steel
    counter_sink_diameter: 6.6
    diameter: 3
    drive_depth: 1.1
    drive_width: 2
    head_diameter: 6
    head_angle: 90
    hole_diameter: 3.6
    minor_diameter: 2.5
  M4: &M4
    visible: true
    color: *steel
    counter_sink_diameter: 8.8
    diameter: 4
    drive_depth: 1.5
    drive_width: 2.5
    head_diameter: 8
    head_angle: 90
    hole_diameter: 4.8
    minor_diameter: 3.3

# ---- Switch Options ----
Switch_Options:
  ChocV1: &ChocV1
    cutout: [14, 14]
    height: # overall: 11.0
      stem: 0
      upper: 5.8
      lower: 2.2
      legs: 3
    max_travel: 3.0
    name: ChocV1
    plate_thickness: 1.2
    radius: 0.5
    spacing: [18, 17]
  ChocV2: &ChocV2
    cutout: [14, 14]
    height: # overall: 11.9
      stem: 3.3
      upper: 3.1
      lower: 2.2
      legs: 3.3
    max_travel: 3.2
    name: ChocV2
    plate_thickness: 1.6
    radius: 0.5
    spacing: [18, 17]
  GLP: &GLP
    cutout: [14, 14]
    height: # overall: 12.1
      stem: 3.2
      upper: 3.4
      lower: 2.5
      legs: 3
    max_travel: 3.0
    name: GLP
    plate_thickness: 1.2
    radius: 0.5
    spacing: [18, 17]
  MX: &MX
    cutout: [14, 14]
    height: # overall: 18.5
      stem: 3.6
      upper: 6.6
      lower: 5
      legs: 3.3
    max_travel: 4.0
    name: MX
    plate_thickness: 1.6
    radius: 0.5
    spacing: [19, 19]
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

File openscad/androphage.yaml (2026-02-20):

# Androphage parameters
# This is a superset of Ergogen YAML.
# Ergogen Config
meta:
  engine: 4.2.1
  version: 0.1
  author:
units:
  ux: 18
  uy: 17
  thumblength: 96
  pcbedge: 4
  $default_height: 17
  $default_padding: 17
  $default_spread: 18
  $default_width: 18
points:
  zones:
    thumb:
      key:
        spread: 0
      rows:
        home:
      columns:
        inner:
          key:
            stagger: -uy
            spread: -ux
        home:
          key:
            origin: [ 0, -thumblength ]
            splay: -11.75
          rows:
            home:
            top:
        outer1:
          key:
            origin: [ 0, -thumblength ]
            splay: -11.75
        outer2:
          key:
            origin: [ 0, -thumblength ]
            splay: -11.75
    fingers:
      anchor:
        ref: thumb_outer2_home
        shift: [ -ux, uy ]
      rows:
        bottom:
        home:
        top:
      columns:
        inner:
        index:
          rows:
        middle:
          key:
            stagger: uy / 2
          rows:
            bottom2:
              shift: [0, -4 * uy]
        ring:
          key:
            origin: [ -ux / 2, -uy ]
            splay: -5
            stagger: -uy / 2
          rows:
            bottom2:
              shift: [ 0, -4 * uy ]
        pinky:
          key:
            origin: [ -ux / 2, -uy / 2]
            splay: -10
            stagger: -uy / 2
        outer:
          $skip: true # Comment out this line to include this column.
outlines:
  _outline:
    - what: polygon
      points:
        - ref: thumb_inner_home
          shift: [-ux/2, uy/2]
        - ref: fingers_inner_top
          shift: [-ux/2, uy/2]
        - ref: fingers_middle_top
          shift: [0, uy/2]
        - ref: fingers_pinky_top
          shift: [ux/2, uy/2]
        - ref: fingers_pinky_bottom
          shift: [ux/2, -uy/2]
        - ref: fingers_ring_bottom2
          shift: [0, -uy/2]
        - ref: thumb_outer2_home
          shift: [0, -uy/2]
        - ref: thumb_home_home
          shift: [0, -uy/2]
        - ref: thumb_inner_home
          shift: [-ux/2, -uy/2]
      expand: pcbedge
      joints: pointy
    - what: circle
      where: thumb_inner_home
      adjust:
        shift: [-20, 0]
      radius: 20
      operation: stack
  _switchcutout:
    - what: rectangle
      size: [13.8, 13.8]
      fillet: 0.4
  _cutouts:
    - what: outline
      name: _switchcutout
      where: true
  switchplate:
    - what: outline
      name: _outline
    - what: outline
      name: _cutouts
      operation: stack
---
# OpenSCAD parameters
components:
  Battery:
    visible: true
    size:
      value: [ 12, 30, 3 ]
      range: [ 0, 100 ]
      description: Dimensions of battery.
  Frame:
    visible: true
    chordAngle:
      value: 5
      range: [ 0, 10 ]
      description: Angle between the chord of the main arc and vertical.
    filletRadius: 1
    lipDepth: 1
    mainRadius: 50
    notchDepth: 6
    thickness:
      value: 5
      range: [ 1, 5 ]
    extraLength: 3
  CenterBlock:
    visible: true
    ribSize: [ 2, 2 ]
    screwCount: 3
    wallThickness: 2
  Desk:
    visible: true
    size: [ 300, 200, 1 ]
    position: [ 0, 0, -40 ]
  Screw:
    visible: true
    diameter: 2
    minorDiameter: 1.6
    headDiameter: 4
    headAngle: 90
    offset: 3
  Insert:
    visible: true
    diameter: 3
    height: 3
    holeDiameter: 2.8
    holeDepth: 4
    wallThickness: 1.6
  Halves:
    visible: true
    angles:
      value: [ 0, 7, 15 ]
      range: [ -45, 45 ]
    clearance: 1
  Hinge:
    visible: true
    diameter: 4.42
    knuckleDepth:
      value: 12.7
      range: [ 0, 25 ]
    length: 90
    leafThickness: 0.04
    leafWidth: 13.5
    offset: 5
    pinDiameter: 2.4
  Keycap:
    visible: true
    clearance: 1
    testClearance: false
    profile:
      value: lame
      range: [ cherry, dsa, lame, mbk, steno ]
    saddle: false
    spacingType:
      value: choc
      range: [ choc, mx, custom ]
    customSpacing: [ 16, 16 ]
  LED:
    visible: true
    present: true
    count: 4
    holeRadius: 0.2
    holeShape:
      value: square
      range: [ square, circle ]
    holeSize: 3
    holeSpacing: [ 4.5, 0 ]
    positionY: -13
  MagneticConnector:
    visible: true
    size: [ 4.7, 26.5, 6.0 ]
    lip: [ 1.0, 28.5, 8.0 ]
    lipOffset: 1.0
  MCU:
    visible: true
    chipSize: [ 12, 10, 1.5 ]
    location:
      value: main PCB
      range: [ trackball sensor, magnetic connector, main PCB ]
    radius: 2
    size: [ 17.8, 21, 1.2 ]
    usbOverhang: 1.5
    usbRadius: 1.2
    usbSize: [ 9, 7.35, 3.2 ]
    usbCutSize: [ 12, 10, 7 ]
  OLED:
    visible: true
    present: false
    holeRadius: 0.5
    pcbSize: [ 15.5, 13 ]
    position: [ 0, 0 ]
    screenSize: [ 12.58, 6.98 ]
  PCB:
    visible: true
    color: DarkGreen
    thickness: 1.2
  BottomPlate:
    visible: true
    thickness:
      value: 1.2
      range: [ 1, 2, 0.2 ]
    clearance:
      value: 3
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

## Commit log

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2025-11-28 Replace KB2040 with XIAO nRF, work on PCB routing.
    [unikyria.kicad_pcb, unikyria.kicad_sch]
2025-12-10 Clean up folder structure.
    [Left.kicad_sch, Right.kicad_sch, androphage.kicad_pcb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]
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2025-12-11 Create VIK hat for Seeed Xiao nRF.
    [Left.kicad_sch, Xiao_VIK_Hat.kicad_sch, androphage-AssemblyMainSketch.dxf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]
2025-12-13 Tentatively finish PCB design.
    [Left.kicad_sch, Left_Switches.kicad_sch, Right.kicad_sch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]
2025-12-16 Work on mechanical design.
    [androphage-AssemblyPlate.step, androphage.FCStd, androphage.scad]
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2025-12-30 Expose plate sketch points as functions.
    [plate_sketch.scad]
2026-01-06 Refactor parameters to not use objects.
    [androphage.scad, androphage_assembly.scad, androphage_globals.scad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]
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2026-01-12 Increase tent to 7 degrees.
    [androphage.scad, androphage_globals.scad]
2026-01-23 Add thumb cluster notch to frame.
    [androphage.scad, androphage_globals.scad, frame.scad]
2026-01-23 Clean up CAD files.
    [androphage-AssemblyMainSketch.dxf, androphage-AssemblyPlate.step, androphage.FCStd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]
2026-01-23 Work on path framework to reconcile plates with frame.
    [frame.scad]
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2026-01-24 Finish the necessary parts of the path library.
    [frame.scad]
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2026-01-25 Fix hard-coded notch cutter dimension.
    [frame.scad]
2026-01-25 Move items to openscad_library.
    [choc_switch.scad]
2026-01-25 Start converting bottom plate to use path library.
    [bottom_plate.scad]
2026-01-25 Rename some hinge parameters.
    [hinge.scad]
2026-01-25 Start refactoring to re-enable Configurator, reduce file size, and improve modularity.
    [androphage.scad, androphage_globals.scad, assembly.scad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]
2026-01-26 Move global declarations to separate file.
    [androphage.scad, globals.scad]
2026-01-26 Move parameter calculations to separate file.
    [derives.scad, objects.scad]
2026-01-26 Start updating component files with new structure.
    [battery.scad, bottom_plate.scad, btu.scad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]
2026-01-26 Add missing parameters to objects.
    [androphage.scad, objects.scad]
2026-01-26 Update more components with new structure.
    [magnetic_connector.scad, mcu.scad, plates_common.scad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]
2026-01-27 Change indentation to spaces.
    [androphage.scad, assembly.scad, battery.scad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]
2026-01-27 Minor reorganization of definitions.
    [androphage.scad, derives.scad, objects.scad]
2026-01-27 More minor definition reorganization.
    [androphage.scad, derives.scad, objects.scad]
2026-01-27 Rewrite plate code from scratch.
    [bottom_plate.scad, key_placement.scad, plate.scad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]
2026-01-28 Add cluster cutout parameter.
    [androphage.scad, objects.scad]
2026-01-28 Unify plate and PCB code.
    [bottom_plate.scad, pcb.scad, plate.scad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]
2026-01-28 Start updating main files with new structure.
    [androphage.scad, assembly.scad, objects.scad]
2026-01-29 Change from using "use" to import components to using "include". Remove circular includes.
    [androphage.scad, battery.scad, btu.scad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]
2026-01-29 Update components to reflect the use of "include" rather than "use".
    [androphage.scad, assembly.scad, battery.scad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]
2026-01-30 Revert to non-object parameters.
    [androphage.scad, assembly.scad, battery.scad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]
2026-02-01 Fix misalignment of plates and frame.
    [androphage.scad, derives.scad, key_placement.scad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]
2026-02-01 Clean up dead code.
    [battery.scad, btu.scad, center_block.scad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]
2026-02-01 Add cutouts to plates for trackball & sensor.
    [androphage.scad, assembly.scad, plates.scad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]
2026-02-01 Fix cutouts in center block for hinges and top plate.
    [assembly.scad, center_block.scad, derives.scad]
2026-02-01 Adjust magnetic connector placement, add cutout to PCB and switch plate.
    [androphage.scad, center_block.scad, derives.scad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]
2026-02-01 Add fillets to LED holes.
    [androphage.scad, plates.scad]
2026-02-02 Clean up dead code in androphage.scad.
    [androphage.scad]
2026-02-02 Fix key cutouts in hinge.
    [assembly.scad, hinge.scad, key_placement.scad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]
2026-02-03 Add USB cutout to MCU.
    [androphage.scad, assembly.scad, mcu.scad]
2026-02-03 Fix frame height.
    [derives.scad]
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2026-02-03 Start rewriting key placement module.
    [keys.scad]
2026-02-09 Rewrite switch and keycap placement code.
    [androphage.scad, assembly.scad, center_block.scad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]
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2026-02-11 - Adapt nrfmicro schematic for control and power components. - Copy key matrix schematics from old KiCAD project.
    [androphage.kicad_sch, control.kicad_sch, left_switches.kicad_sch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]
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2026-02-12 Add option to export switch plate sketch DXF for PCB design.
    [androphage.scad, assembly.scad, plates.scad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]
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2026-02-19 Create script for converting Ergogen YAML to OpenSCAD.
    [ergogen.scad]
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2026-03-31 Align plate front center corner with origin and fix a few bugs.
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2026-04-08 Make case height driven by the key height or trackball radius, whichever is greater.
    [keycaps.csv]
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2026-04-09 Fix collisions between frame and center block.
    [androphage.yaml]
2026-04-10 Start removing collisions between plates and center block.
    [androphage.yaml]
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2026-04-18 Fix frame screw locations.
2026-04-20 Add clearance between frame and PCB/switch plate.
    [androphage.yaml]
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2026-04-30 Fix frame location.
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2026-05-01 Fix position of hinge cutouts.
    [androphage.yaml]
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2026-05-12 Fix magnetic connector lip location.
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2026-05-12 Redesign knife hinge.
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2026-05-14 FIx plate DXF export.
    [bottom.dxf, pcb.dxf, switch.dxf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]
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2026-05-15 Refactor center block module to use algebra mode.
    [bottom.dxf, pcb.dxf, switch.dxf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]
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2026-05-24 Add the rest of the hinge parts to the assembly.
    [knife_hinge.step]
2026-05-24 Expand hinge production file script to export DXFs and multi-part STEP.
    [hinge_knuckle_plate.dxf, hinge_plate.dxf, knife_hinge.step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]
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2026-06-08 Fix PCB and switch plate positioning.
    [bottom.dxf, pcb.dxf, switch.dxf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]
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2026-06-24 Adjust base shape for better stability.
    [androphage.yaml]
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2026-07-04 Rework PCBs to ensure adequate clearance between them.
    [bottom_plate.kicad_pcb, left.kicad_sch, matrix_plate.kicad_pcb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]
2026-07-04 Reduce trackball sensor PCB width and ensure clearance for all components.
    [androphage.yaml]
2026-07-04 Fix USB cutout placement in the frame.
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2026-07-08 Fix keycap orientations.
    [Choc_Chicago_Steno_r0.stl]
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2026-07-09 Miscellaneous bug fixes.
    [bottom.dxf, case_combined.step, case_combined.stl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]
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2026-07-10 Move all components to top of matrix plate to improve manufacturability.
    [left.kicad_sch, matrix_plate.kicad_pcb]
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2026-07-20 Correct Schottky diode footprint from SOD-323 to SOD-123.
    [bottom_plate.kicad_pcb, right.kicad_sch]
2026-07-20 Move diodes to front of matrix plates for cheaper assembly.
    [left.kicad_sch, matrix_plate.kicad_pcb, matrix_plate.kicad_sch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]
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2026-07-20 Continue re-routing matrix plate to move diodes to front.
    [matrix_plate.kicad_pcb]
2026-07-20 Reduce switch plate thickness to ensure clearance for PCB components.
    [bottom.dxf, bottom.stl, pcb.dxf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]
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2026-08-05 Update KiCAD projects to use new library locations.
    [bottom_plate.kicad_pcb, left.kicad_sch, matrix_plate.kicad_pcb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]
